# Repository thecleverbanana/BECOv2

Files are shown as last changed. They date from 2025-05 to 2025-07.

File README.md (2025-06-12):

# BECOv2
This repo is aimed for RoboLAND and experiment on Multi-Agent Robot

The repo is divided into four parts: Mega 2560, simulation, analysis and CAD 

### Mega 2560 
This part is directly communicating with our actual rebot using mega 2560 micro-controller unit. 

Before running the controller, please read followings:

#### A. Wiring 


There are two major connections:

1. **UART (RX/TX) with LSS motor**  
   **Important**: please double check the wire direction of the power and ground of the LSS wire:  [See official wiring guide](https://wiki.lynxmotion.com/info/wiki/lynxmotion/view/ses-v2/lynxmotion-smart-servo/lss-electrical/)
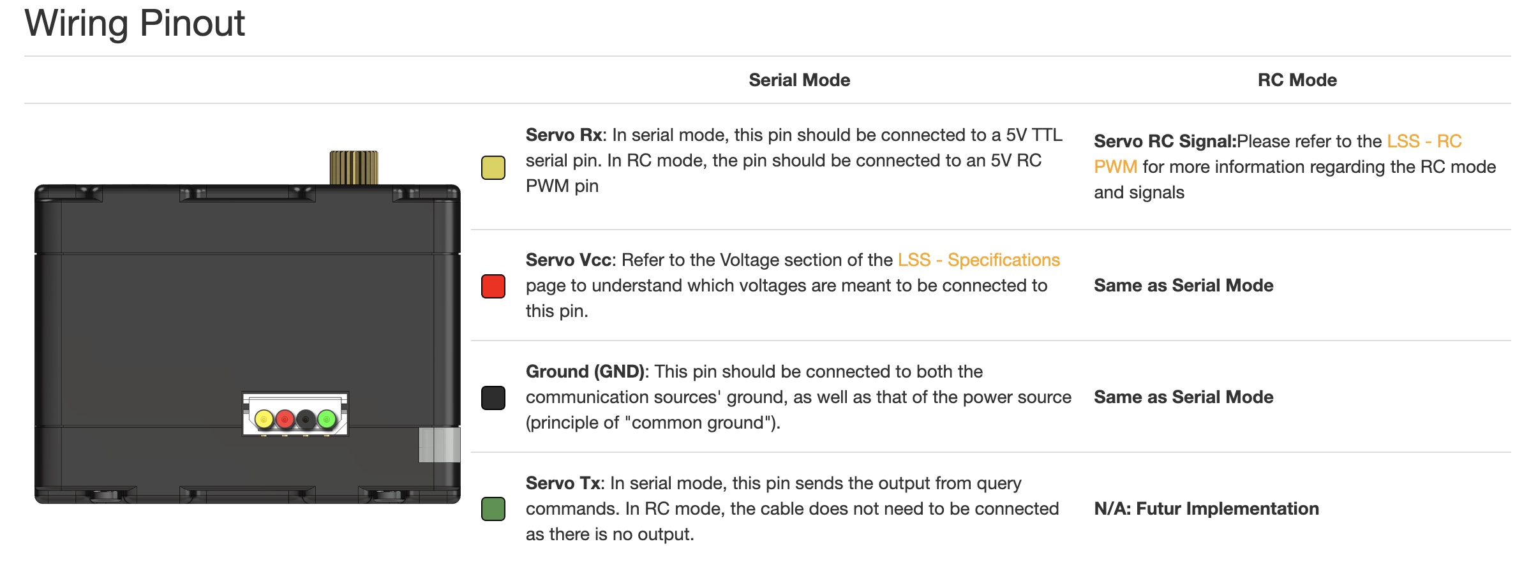
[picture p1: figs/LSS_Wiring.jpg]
     

   We used Serial1 from Mega 2560 to communicate with the motor, which corresponds to pin 18 (TX1) and pin 19 (RX1) on the board.

2. **PWM with linear actuator**  
   We used pin 4 (PWM capable) to connect with the linear actuator.  
   Make sure the blue wire matches the blue wire on the actuator.  
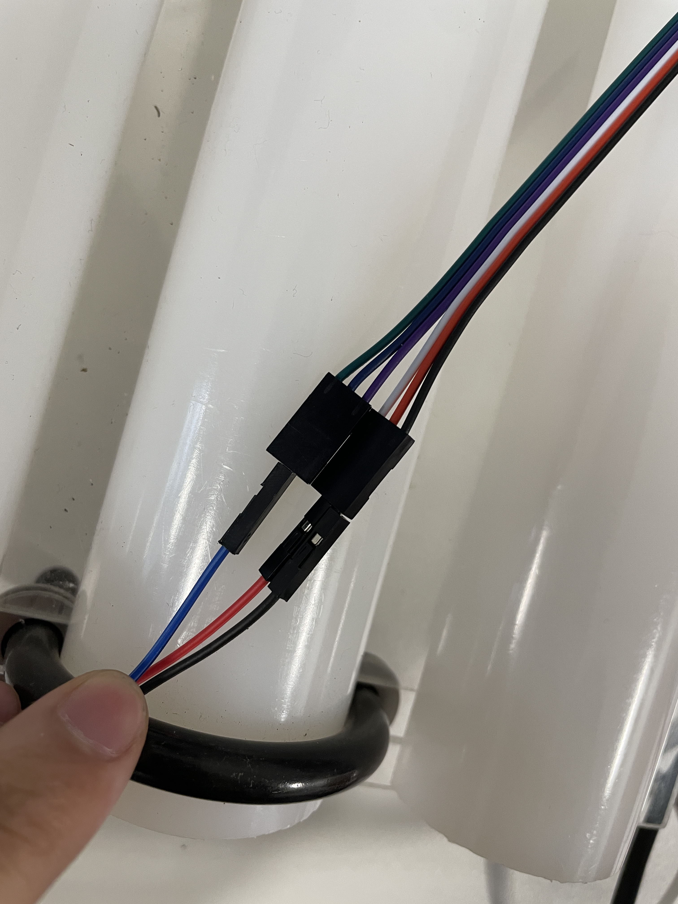
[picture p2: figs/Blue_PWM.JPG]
     

All the wiring directions are marked, please check the markers:  
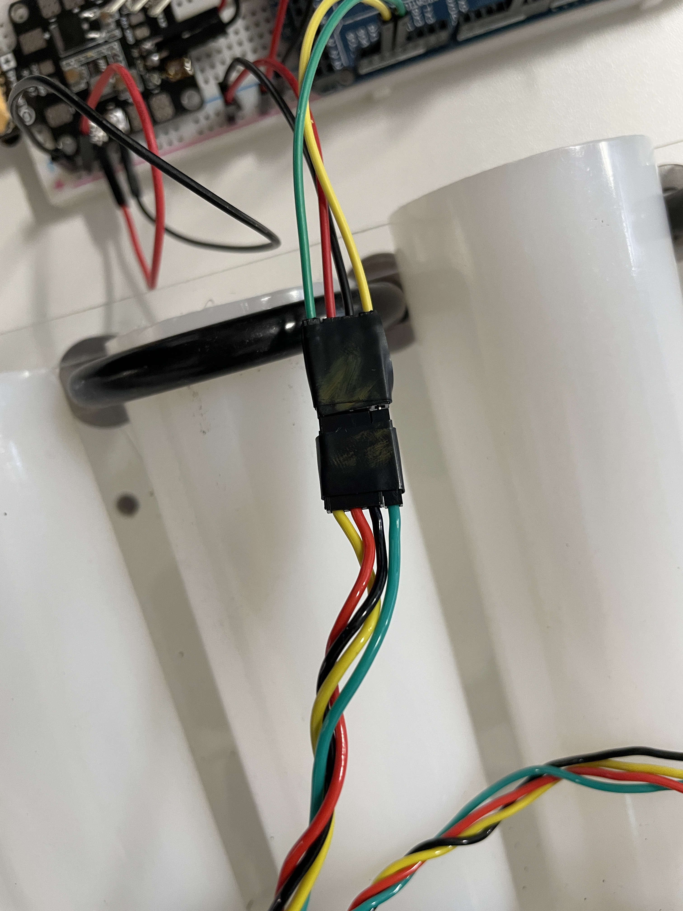
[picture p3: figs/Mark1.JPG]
    

#### B. Power
1. Power should be connected to the PDB with maxium 12V and minimum 6V. And current should never exceed 1A, 650mA is enough
2. Power for linear actuator and motor are both 12 V.
#### B. Coding
1. Download platformIO from vscode extensions
2. Main file in src, use platformIO to compile (main.cpp is the interface with platform io, if you want to run different code, simply copy code into main.cpp or modify compiling path in platformio.ini)

### Simulation
This part is used for robot simulation. We used the Webots and Gazebo as simulation platform.

### Analysis
All analysis code and documentation can be found here 

### CAD
All needed CAD files of our robot can be found here

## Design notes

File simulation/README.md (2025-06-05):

# Some useful commands and instructions for simulation

### urdf to proto    https://github.com/cyberbotics/urdf2webots 
python3 -m urdf2webots.importer \
  --input="/Users/jerrywu/Library/Mobile Documents/com~apple~CloudDocs/Desktop/Roboland/Multi-Agent/BECOv2/simulation/Webots/urdf/BECOV2.urdf" \
  --output="/Users/jerrywu/Library/Mobile Documents/com~apple~CloudDocs/Desktop/Roboland/Multi-Agent/BECOv2/simulation/Webots/protos/BECOV2BOX.proto" \
  --normal

### Solid format in world
Solid {
  translation 0 0 0 
  rotation 1 0 0 1.5708
  children [
    Shape {
      appearance PBRAppearance {
        baseColor 0.2 0.2 1.0
        roughness 0.5
        metalness 0.0
      }
      geometry Mesh {
        url "../../Blender/Terrain/terrain7/terrain7.obj"
      }
    }
  ]
  boundingObject Mesh {
    url "../../Blender/Terrain/terrain7/terrain7.obj"
  }
  physics Physics {
    mass 10
  }
  name "Terrain7"
}

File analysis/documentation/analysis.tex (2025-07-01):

\documentclass[11pt]{article}

% --- Encoding & Language ---
\usepackage[utf8]{inputenc}
\usepackage[T1]{fontenc}
\usepackage[english]{babel}

% --- Math Packages ---
\usepackage{amsmath, amssymb, amsfonts}
\usepackage{mathtools}
\usepackage{physics}          % for \dv, \pdv, \grad, etc.
\usepackage{bm}               % for bold math symbols
\usepackage{siunitx}          % for units

% --- Page Layout ---
\usepackage[margin=1in]{geometry}
\usepackage{setspace}
\onehalfspacing

% --- Theorem Environment ---
\usepackage{amsthm}
% Create a shared counter (let's call it 'statement') per section
\newtheorem{statement}{Statement}[section]
\newtheorem{theorem}[statement]{Theorem}
 
% Define 'assumption' and 'diagram' to use the same counter
\newtheorem{assumption}[statement]{Assumption}
\newtheorem{diagram}[statement]{Diagram}
\newtheorem{note}[statement]{Note}

% --- Figure & Table ---
\usepackage{graphicx}
\usepackage{float}
\usepackage{caption}
\usepackage{subcaption}
\usepackage{mwe}
% \includegraphics{example-image}
\usepackage{hyperref}

% --- TikZ for Diagrams ---
\usepackage{tikz}
\usetikzlibrary{arrows.meta, decorations.pathmorphing, patterns}

% --- Code Listings (optional) ---
\usepackage{listings}
\lstset{
  basicstyle=\ttfamily\small,
  frame=single,
  breaklines=true,
  postbreak=\mbox{\textcolor{red}{$\hookrightarrow$}\space},
}

% --- Title Info ---
\title{\textbf{Force Based Model Analysis}}
\author{Jerry Wu}
\date{\today}

\begin{document}

\maketitle
\noindent
\textbf{Helpful Link:}
\begin{itemize}
    \item \href{https://www.geogebra.org/classic/vzgc97bq}{Geogebra Demo}
    \item \href{https://www.canva.com/design/DAGo-OCr6Yo/K5YV57vaBxux-PqkqwI4ow/edit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}{Canva Graphics}
\end{itemize}

% \begin{assumption}\label{ass:leg-ground-contact}
% The end point of each leg is always contacting the ground.
% \end{assumption}

\begin{assumption}\label{ass: no-body-contact}
The robot body would never contact with the terrain
\end{assumption}

\begin{assumption}\label{ass: com}
The CoM of the robot is always at local geometric center in direction parrallel to Spine
\end{assumption}

\section{Statics}
\begin{assumption}
Static means the robot would not move and achieve static equilibrium in this state
\end{assumption}
\subsection*{Slope}

\begin{diagram}
    Simple case where two legs have same height
\end{diagram}\label{ass:h2-equal-h1}
\vspace{1ex} % small vertical space
\begin{center}
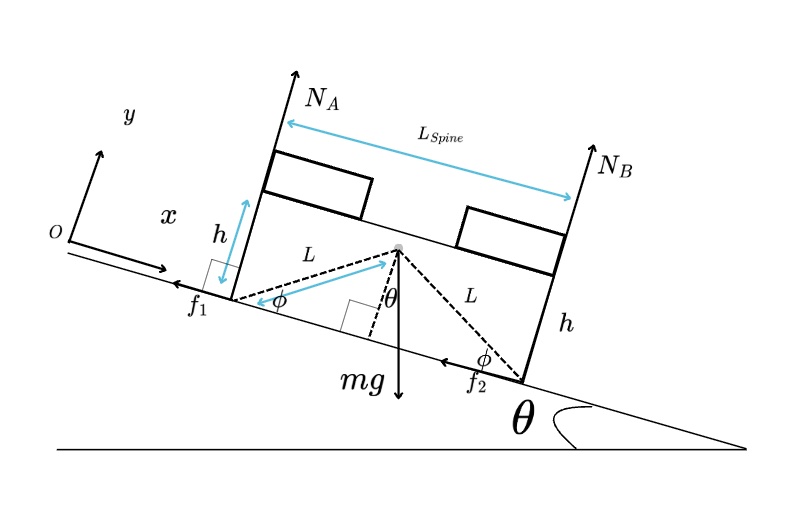
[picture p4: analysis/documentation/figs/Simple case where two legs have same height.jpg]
     % replace with your image
\end{center}

To start with,  we put robot on a slope with angle \(\theta\). To make the analysis easier,
assume that two leg have same height \(h\) in this case. Therefore, the moment arm are symetric
for \(R_A\) and \(R_B\). Therefore, we can get follow equations:
\[ \sum F_x = (f_1+f_2) - \sin(\theta)mg = 0 \]
\[ \sum F_y = (N_A+N_B) - \cos(\theta)mg = 0 \]
\[ \sum M_A = L_\text{spine} \cdot N_B -  L \cdot mg \cdot \sin(\frac{\pi}{2}-\phi+\theta) = 0 \]
\[ \sum M_B = L_\text{spine} \cdot N_A -  L \cdot mg \cdot \sin(\frac{\pi}{2}-\phi+\theta) = 0 \]

\begin{diagram}
    Two legs have different height
\end{diagram}\label{ass:h2-larger-than-h1}
\vspace{1ex} % small vertical space
\begin{center}
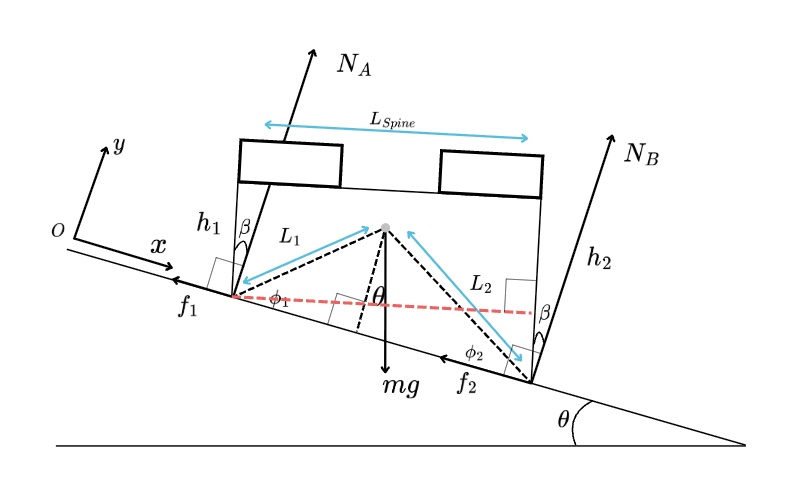
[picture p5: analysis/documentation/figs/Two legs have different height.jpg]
     % replace with your image
\end{center}

Now extend the case to where the leg length would change. Here the robot extended
the right leg to \(h_2\), which makes the robot rotate angle \(\beta\) around
the z-Axis. Now both moment arms on two legs are 
shifted. We can also form the static equilibrium equation as follows:

\[ \sum F_x = (f_1+f_2) - \sin(\theta)mg = 0 \]
\[ \sum F_y = (N_A+N_B) - \cos(\theta)mg = 0 \]
\[ \sum M_A = \frac{L_\text{spine}}{\sin(\frac{\pi}{2}-\beta)} \cdot N_B \cdot \sin(\frac{\pi}{2})-  L_1 \cdot mg \cdot \sin(\frac{\pi}{2}-\phi_1+\theta) = 0 \]
\[ \sum M_B = \frac{L_\text{spine}}{\sin(\frac{\pi}{2}-\beta)} \cdot N_A \cdot \sin(\frac{\pi}{2})-  L_2 \cdot mg \cdot \sin(\frac{\pi}{2}-\phi_2-\theta) = 0 \]

based on the geometry of our robot, we can also formulate:
\[L_\text{spine} \cdot \cos(\frac{\pi}{2}-\beta) = h_2 - h_1 \]

\begin{note}\label{not:what-is-known}
\(h_1\), \(h_2\) are known values, so \(\beta\) is also known.  
Therefore, \(\phi_1\) and \(\phi_2\) can easily be solved using Theorem~\ref{thm:law-of-cosines}.
\end{note}

\begin{theorem}\label{thm:law-of-cosines}
Law of Cosines

\[
\cos A = \frac{b^2 + c^2 - a^2}{2bc}
\]
\[
\cos B = \frac{a^2 + c^2 - b^2}{2ac}
\]
\[
\cos C = \frac{a^2 + b^2 - c^2}{2ab}
\]
\end{theorem}

\subsection*{Zig-Zag Terrain}

\begin{assumption}\label{ass:Zig-Zag-terrain-assumption}
The terrain is uniform that all triangle obstable and gap between them are same
\end{assumption}

A natural extension for the slope is triangle terrain. There are esseintially five cases
when robot is static on the triangle terrain: 1. two legs on the same slope 2. two legs on two slopes that face each other
3. two legs on two slopes that does not face each other 4. one leg is on the slope and the other is on the gap. 5. two legs
are all on the gap. 

For case 1, we have already discussed in the previous section. And for case 5, it is esseintially the same
like slope when \(\theta\) is 0.

\begin{diagram}
    Case2: two legs on the slope that face each other
\end{diagram}
\vspace{1ex} % small vertical space
\begin{center}
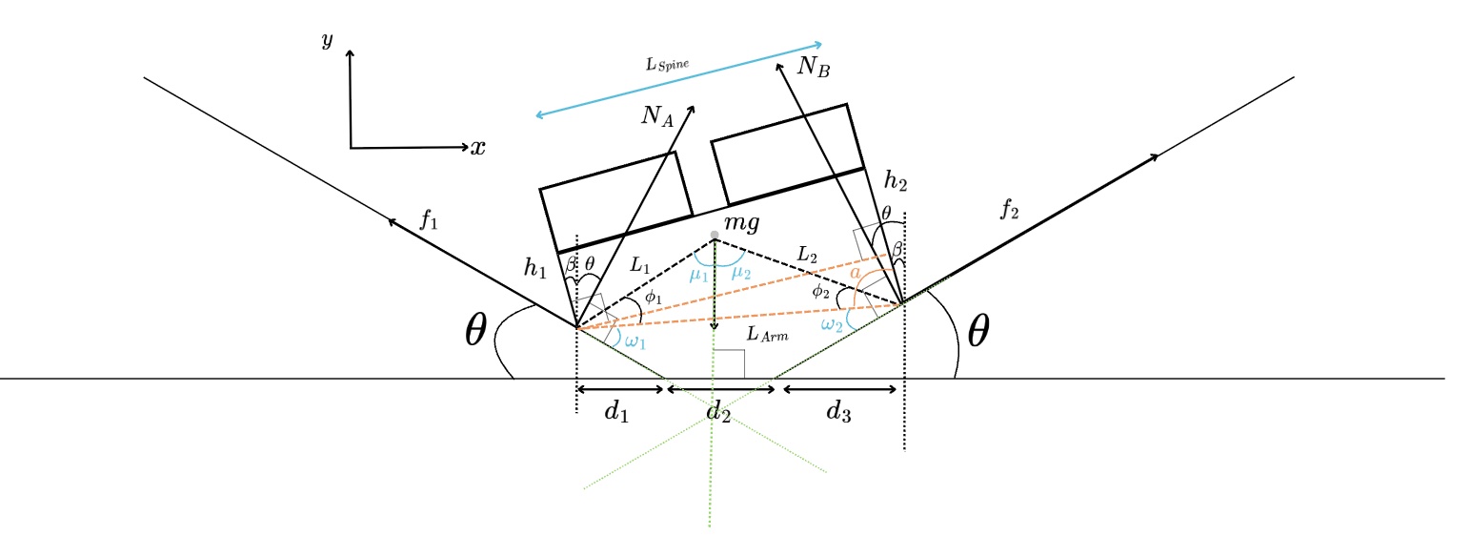
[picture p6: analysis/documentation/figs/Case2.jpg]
     % replace with your image
\end{center}

To make it clearer, I changed the coordinate that aligns with the ground rather slope from now on.
We can also formulate the equilibrium equations:

\[ \sum F_x = (-f_1+f_2)\cos(\theta) + (N_A-N_B) \sin(\theta) = 0 \]
\[ \sum F_y = (f_1+f_2)\sin(\theta) + (N_A+N_B) \cos(\theta) - mg = 0 \]
\[ \sum M_A =  L_\text{Arm} \cdot (N_B \cdot \sin(\frac{\pi}{2}-\omega_2) + f_2 \cdot \sin(\pi-\omega_2)) - L_1\cdot mg \cdot \sin(\mu_1)= 0 \]
\[ \sum M_B =  L_\text{Arm} \cdot (N_B \cdot \sin(\frac{\pi}{2}-\omega_1) + f_1 \cdot \sin(\pi-\omega_1)) - L_2\cdot mg \cdot \sin(\mu_2)= 0 \]

where by geometry of the shape, we can find:
\[\omega_1 = (\theta + \beta)  - (\frac{\pi}{2}-\alpha) \]
\[\omega_2 = (\theta - \beta) + (\frac{\pi}{2}-\alpha) \]
\[\mu_1 = \pi-(\phi_1+\omega_1)-(\frac{\pi}{2}-\theta) \]
\[\mu_2 = \pi-(\phi_2+\omega_2)-(\frac{\pi}{2}-\theta) \]
\[\alpha = \arctan(\frac{L_\text{Spine}}{h2-h1}) \]
\[L_\text{Arm} = \sin(\alpha) \cdot L_\text{Spine}\]

similarly to Note~\ref{not:what-is-known}, this equalion can be solved.

\begin{diagram}
    Case3: two legs on two slopes that do not face each other
\end{diagram}
\vspace{1ex} % small vertical space
\begin{center}
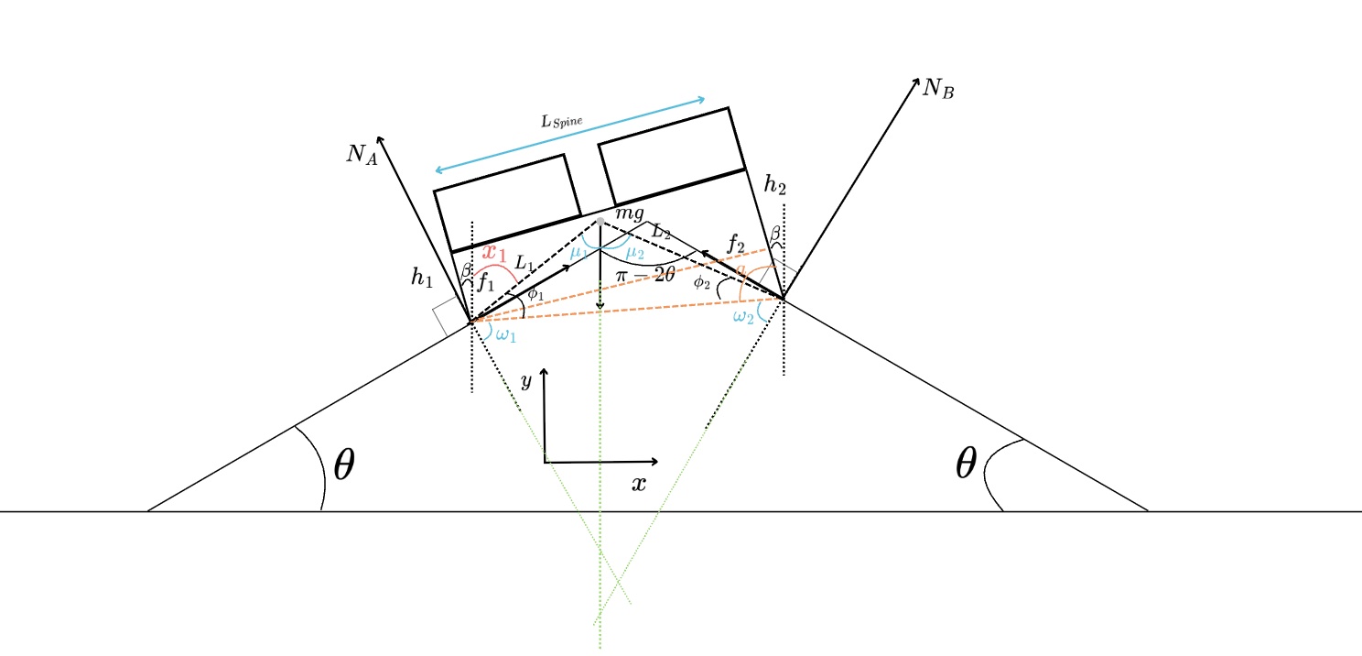
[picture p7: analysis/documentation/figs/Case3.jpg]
     % replace with your image
\end{center}

\[ \sum F_x = (f_1-f_2)\cos(\theta) + (-N_A+N_B) \sin(\theta) = 0 \]
\[ \sum F_y = (f_1-f_2)\sin(\theta) + (-N_A+N_B) \cos(\theta) - mg = 0 \]
\[ \sum M_A =  L_\text{Arm} \cdot (N_B \cdot \sin(\pi-\omega_2) + f_2 \cdot \sin(\frac{\pi}{2}-\omega_2)) - L_1\cdot mg \cdot \sin(\mu_1)= 0 \]
\[ \sum M_B =  L_\text{Arm} \cdot (N_A \cdot \sin(\pi-\omega_1) + f_1 \cdot \sin(\frac{\pi}{2}-\omega_1)) - L_2\cdot mg \cdot \sin(\mu_2)= 0 \]

where by geometry of the shape, we can find:
\[\omega_1 = \beta + \alpha - \theta\]
\[\omega_2 =  \pi - \beta - \alpha - \theta\]
\[\mu_1 = \pi-(\phi_1+\omega_1)-\theta \]
\[\mu_2 = \pi-(\phi_2+\omega_2)-\theta \]
\[\alpha = \arctan(\frac{L_\text{Spine}}{h2-h1}) \]
\[L_\text{Arm} = \sin(\alpha) \cdot L_\text{Spine}\]

\begin{note}
The equation for \(\omega_1\)  can be found specifically by following equation:
\end{note}
\begin{equation}
x_1 + \phi_1 + \omega_1 + \theta = \pi
\end{equation}

\begin{equation}
\beta + x_1 + \phi_1 - \left( \frac{\pi}{2} - \alpha \right) = \frac{\pi}{2}
\end{equation}

\begin{equation}
\omega_1 = \beta + \alpha - \theta
\tag*{From (1) and (2)}
\end{equation}

\begin{diagram}
    Case4: one leg is on the slope and the other is on the gap
\end{diagram}
\vspace{1ex} % small vertical space
\begin{center}
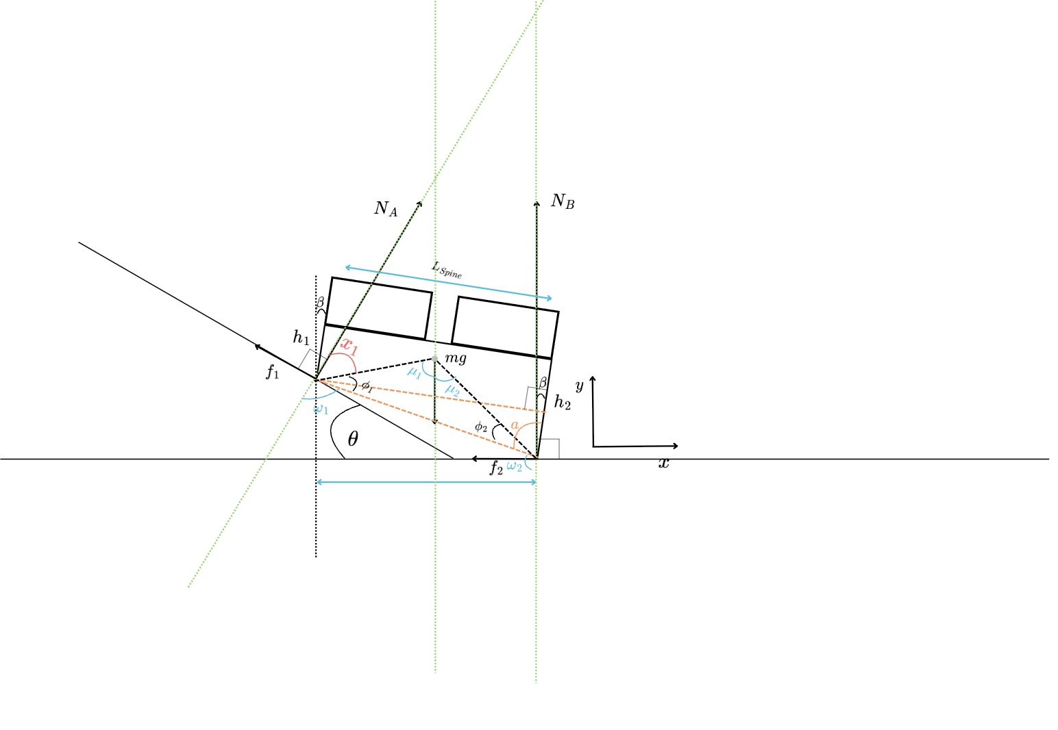
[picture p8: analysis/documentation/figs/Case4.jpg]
     % replace with your image
\end{center}

\[ \sum F_x = -f_1 \cos(\theta) -f_2 + N_A \sin(\theta)= 0 \]
\[ \sum F_y = f_1 \sin(\theta)+ N_A \cos(\theta) + N_B - mg = 0 \]
\[ \sum M_A =  L_\text{Arm} \cdot (N_B \cdot \sin(\pi-\omega_2) + f_2 \cdot \sin(\frac{\pi}{2}-\omega_2)) - L_1\cdot mg \cdot \sin(\mu_1)= 0 \]
\[ \sum M_B =  L_\text{Arm} \cdot (N_B \cdot \sin(\pi-\omega_1) + f_1 \cdot \sin(\frac{3\pi}{2}-\omega_1)) - L_2\cdot mg \cdot \sin(\mu_2)= 0 \]

where by geometry of the shape, we can find:
\[\omega_1 = \theta - \beta + \alpha\]
\[\omega_2 =  \pi + \beta - \alpha \]
\[\mu_1 = \pi-(\phi_1+\omega_1)-\theta \]
\[\mu_2 = \pi-(\phi_2+\omega_2) \]
\[\alpha = \arctan(\frac{L_\text{Spine}}{h2-h1}) \]
\[L_\text{Arm} = \sin(\alpha) \cdot L_\text{Spine}\]

\begin{note}
The equation for \(\omega_1\)  can be found specifically by following equation:
\end{note}
\begin{equation}
x_1 + \phi_1 + \omega_1 = \pi
\end{equation}

\begin{equation}
\theta-\beta + x_1 + \phi_1 - \left( \frac{\pi}{2} - \alpha \right) = \frac{\pi}{2}
\end{equation}

\begin{equation}
\omega_1 = \theta - \beta + \alpha
\tag*{From (1) and (2)}
\end{equation}

Now, by observation, this case is very similar to previous case. In fact, all of the above cases
are geometrically similar, which means we can find a general expression for this force based model.

\begin{diagram}
    Determine the geometry shape by robot body and terrain
\end{diagram}
\vspace{1ex} % small vertical space
\begin{center}
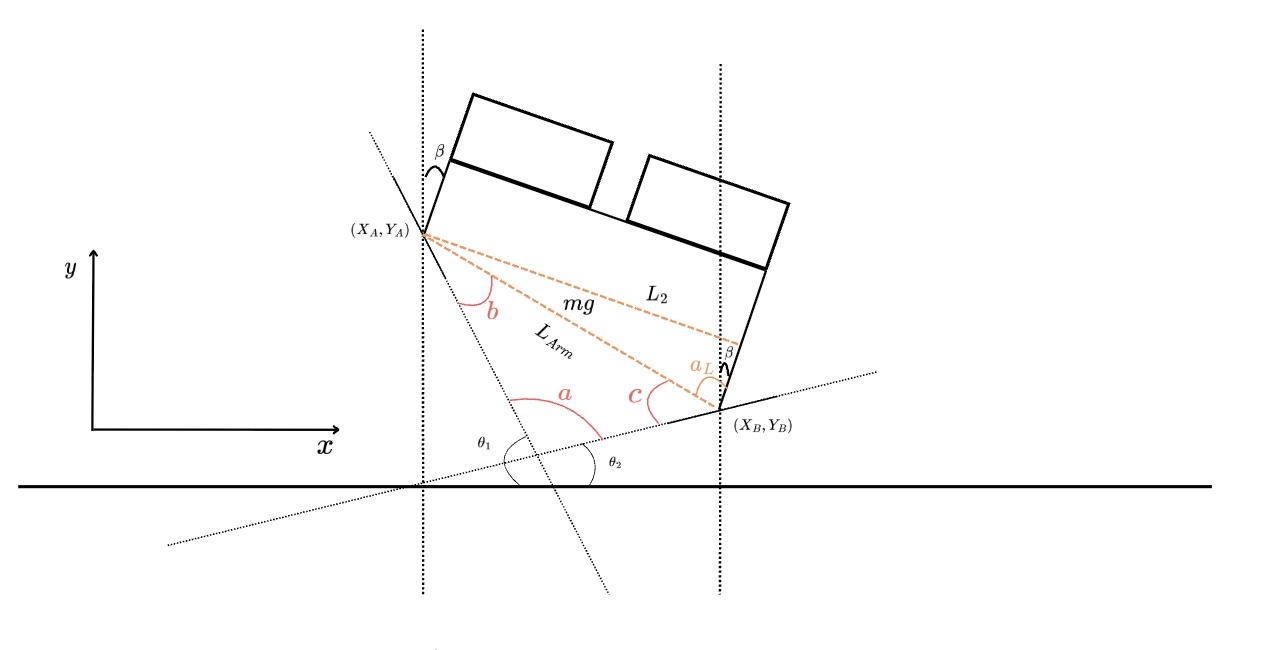
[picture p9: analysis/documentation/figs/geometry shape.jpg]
     % replace with your image
\end{center}

After simplifying the model, it can be seen that given the terrain tangent angle \(\theta_1\), \(\theta_2\), robot pitch
angle \(\beta\) and length of the virtual link between end point of two leg \(L_{Arm}\) we can determine the triangle with
inner angle \(a,b,c\). 

Here is how we determine angle \(a, b, c\):
\[a = \pi - \theta_1 - \theta_2\]
\[b = \pi - \beta - \frac{\pi}{2}-(\frac{\pi}{2}-\alpha_L)-(\pi-\theta_1)\]
\[c = \pi - (\pi-\theta_2) + \beta - \alpha_L\]

by verification: 
\[a+b+c = \pi\]

As for different tangent angles, this property should hold as well. This means there would be \textbf{only one solution} by
given condition.

\begin{diagram}
    Generailized Free Body Diagram
\end{diagram}
\vspace{1ex} % small vertical space
\begin{center}
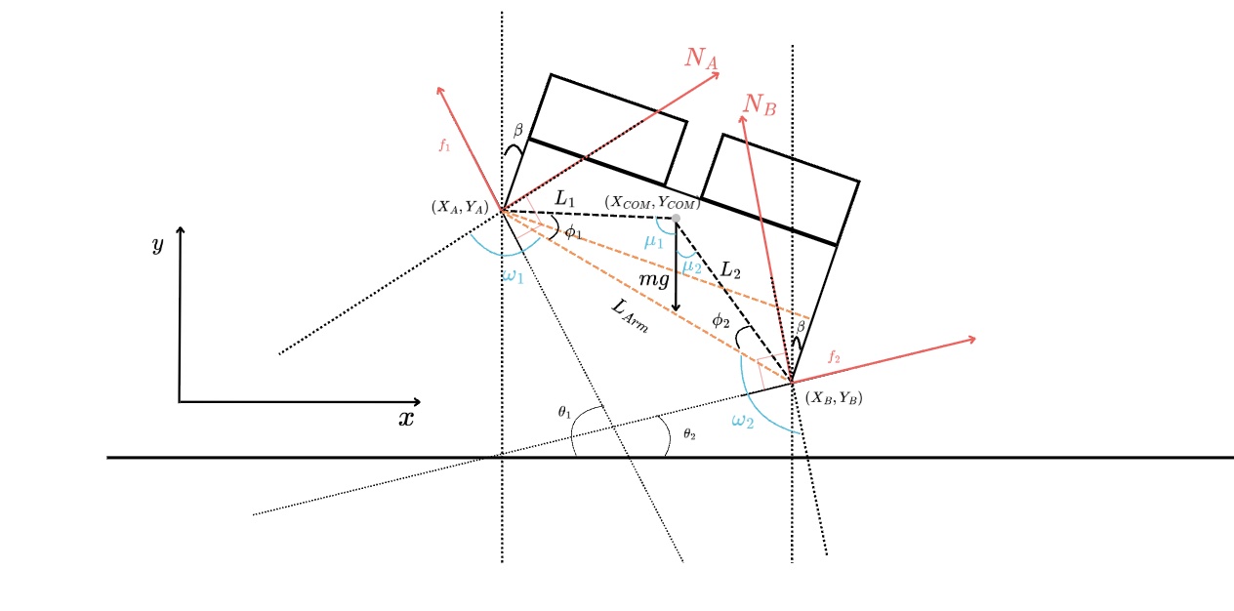
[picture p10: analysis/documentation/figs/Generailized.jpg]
     % replace with your image
\end{center}

Given the determined geometric shape of the robot and terrain, we can easily find the position of the COM through
the given of relative position \(L_1\) and \(L_2\), which can be solved by the geometry as well. Which means, if we put
the robot into coordinate, the points \((X_A, Y_A), (X_B, Y_B), (X_{COM}, Y_{COM})\) are given.

Therefore, given \((X_A, Y_A), (X_B, Y_B), (X_{COM}, Y_{COM}), \theta_1, \theta_2\), \(L_{Spine}\) we can formulate
\[
\sum \vec{F} = \vec{f}_1 + \vec{f}_2 + \vec{N}_A + \vec{N}_B + \vec{W} = \vec{0}
\]

\[
\sum \vec{M}_A = 
(\vec{r}_B - \vec{r}_A) \times (\vec{f}_2 + \vec{N}_B)
+ (\vec{r}_{\text{COM}} - \vec{r}_A) \times \vec{W}
= 0
\]

\[
\sum \vec{M}_B = 
(\vec{r}_A - \vec{r}_B) \times (\vec{f}_1 + \vec{N}_A)
+ (\vec{r}_{\text{COM}} - \vec{r}_B) \times \vec{W}
= 0
\]

where
\begin{align*}
\hat{t}_1 &= (\cos(\pi-\theta_1),\; \sin(\pi-\theta_1)) \quad \text{(contact tangent 1)} \\
\hat{n}_1 &= (-\sin(\pi-\theta_1),\; \cos(\pi-\theta_1)) \quad \text{(contact normal 1)} \\
\hat{t}_2 &= (\cos\theta_2,\; \sin\theta_2) \\
\hat{n}_2 &= (-\sin\theta_2,\; \cos\theta_2)
\end{align*}

\begin{align*}
\vec{f}_1 &= f_1 \cdot \hat{t}_1 = f_1 \cdot (\cos(\pi-\theta_1),\; \sin(\pi-\theta_1)) \\
\vec{N}_A &= N_A \cdot \hat{n}_1 = N_A \cdot (-\sin(\pi-\theta_1),\; \cos(\pi-\theta_1)) \\
\vec{f}_2 &= f_2 \cdot \hat{t}_2 = f_2 \cdot (\cos\theta_2,\; \sin\theta_2) \\
\vec{N}_B &= N_B \cdot \hat{n}_2 = N_B \cdot (-\sin\theta_2,\; \cos\theta_2) \\
\vec{W}   &= -mg \cdot (0,\; 1)
\end{align*}

\begin{align*}
\text{Moment arm of } \vec{f}_2, \vec{N}_B \text{ about A}: \quad
& \vec{r}_{f_2/A} = \vec{r}_B - \vec{r}_A = (X_B - X_A,\; Y_B - Y_A) \\
\text{Moment arm of } \vec{W} \text{ about A}: \quad
& \vec{r}_{W/A} = \vec{r}_{\text{COM}} - \vec{r}_A = (X_{COM} - X_A,\; Y_{COM} - Y_A) \\[1ex]
\text{Moment arm of } \vec{f}_1, \vec{N}_A \text{ about B}: \quad
& \vec{r}_{f_1/B} = \vec{r}_A - \vec{r}_B = (X_A - X_B,\; Y_A - Y_B) \\
\text{Moment arm of } \vec{W} \text{ about B}: \quad
& \vec{r}_{W/B} = \vec{r}_{\text{COM}} - \vec{r}_B = (X_{COM} - X_B,\; Y_{COM} - Y_B)
\end{align*}

Therefore,
\begin{align*}
    \sum \vec{F}_x &= -f_1 \cos\theta_1 + f_2 \cos\theta_2 
                     - N_A \sin\theta_1 - N_B \sin\theta_2 = 0 \\
    \sum \vec{F}_y &= f_1 \sin\theta_1 + f_2 \sin\theta_2 
                     - N_A \cos\theta_1 + N_B \cos\theta_2 - mg = 0 \\[1ex]
    \sum \vec{M}_A &= (X_B - X_A)(f_2 \sin\theta_2 + N_B \cos\theta_2)
                     - (Y_B - Y_A)(f_2 \cos\theta_2 - N_B \sin\theta_2)
                     - mg (X_{\text{COM}} - X_A) = 0 \\
    \sum \vec{M}_B &= (X_A - X_B)(f_1 \sin\theta_1 - N_A \cos\theta_1)
                     - (Y_A - Y_B)(-f_1 \cos\theta_1 - N_A \sin\theta_1)
                     - mg (X_{\text{COM}} - X_B) = 0
\end{align*}

solve,
\begin{align*}
    N_A &= \frac{g m (X_B - X_{\text{COM}}) \cos\theta_1}{X_A - X_B} \\[1ex]
    N_B &= \frac{g m (X_A - X_{\text{COM}}) \cos\theta_2}{X_A - X_B} \\[1ex]
    f_1 &= \frac{g m (X_{\text{COM}} - X_B) \sin\theta_1}{X_A - X_B} \\[1ex]
    f_2 &= \frac{g m (X_A - X_{\text{COM}}) \sin\theta_2}{X_A - X_B}
\end{align*}
    
By friction function \(\left| f \right| \leq \mu N\), we can solve this equation and find 

\begin{align*}
    \left| f_1 \right| &= \left| \frac{g m (X_{\text{COM}} - X_B) \sin\theta_1}{X_A - X_B} \right| 
    \leq \mu \cdot \frac{g m (X_B - X_{\text{COM}}) \cos\theta_1}{X_A - X_B} = \mu N_A \\[1.5ex]
    \left| f_2 \right| &= \left| \frac{g m (X_A - X_{\text{COM}}) \sin\theta_2}{X_A - X_B} \right| 
    \leq \mu \cdot \frac{g m (X_A - X_{\text{COM}}) \cos\theta_2}{X_A - X_B} = \mu N_B
\end{align*}

% \begin{note}
    The above expression is derived in case where the \(\theta_1\) and \(\theta_2\) are both acute angles from graphic
    definition, but it is clear that in other cases, they are the same, a even more genral expression is actually:
% \end{note}

\begin{align*}
    \vec{f}_1 &= f_1 \cdot \hat{t}_1 \\
    \vec{N}_A &= N_A \cdot \hat{n}_1 \\
    \vec{f}_2 &= f_2 \cdot \hat{t}_2 \\
    \vec{N}_B &= N_B \cdot \hat{n}_2 \\
    \vec{W}   &= -mg \cdot (0,\; 1) \\
\end{align*}
\begin{align*}
    \sum F_x &= f_1 t_{1x} + f_2 t_{2x} + N_A n_{1x} + N_B n_{2x} = 0 \\
    \sum F_y &= f_1 t_{1y} + f_2 t_{2y} + N_A n_{1y} + N_B n_{2y} - mg = 0 \\
    \sum M_A &= 
    (x_B - x_A)(f_2 t_{2y} + N_B n_{2y}) - (y_B - y_A)(f_2 t_{2x} + N_B n_{2x}) \notag \\
    &\quad - mg (x_{COM} - x_A) = 0 \\
    \sum M_B &= 
    (x_A - x_B)(f_1 t_{1y} + N_A n_{1y}) - (y_A - y_B)(f_1 t_{1x} + N_A n_{1x}) \notag \\
    &\quad - mg (x_{COM} - x_B) = 0
\end{align*}
In matrix form: 
\begin{align*}
    \scriptsize
    \left[
    \begin{array}{cccc}
    t_{1x} & t_{2x} & n_{1x} & n_{2x} \\
    t_{1y} & t_{2y} & n_{1y} & n_{2y} \\
    0 & \Delta x_{BA} t_{2y} - \Delta y_{BA} t_{2x} 
      & 0 & \Delta x_{BA} n_{2y} - \Delta y_{BA} n_{2x} \\
    \Delta x_{AB} t_{1y} - \Delta y_{AB} t_{1x} 
      & 0 & \Delta x_{AB} n_{1y} - \Delta y_{AB} n_{1x} 
      & 0
    \end{array}
    \right]
    \cdot
    \begin{bmatrix}
    f_1 \\ f_2 \\ N_A \\ N_B
    \end{bmatrix}
    =
    \begin{bmatrix}
    0 \\
    mg \\
    mg (x_{\text{COM}} - x_A) \\
    mg (x_{\text{COM}} - x_B)
    \end{bmatrix}
    \normalsize
\end{align*}
    
\paragraph{Friction Cone Constraints}
\[
|\vec{f}_1| \leq \mu |N_A|, \quad 
|\vec{f}_2| \leq \mu |N_B|
\]

\subsection*{Cylinder Terrain}

\begin{diagram}
    Generailized expression on Cylinder Terrain
\end{diagram}
\vspace{1ex} % small vertical space
\begin{center}
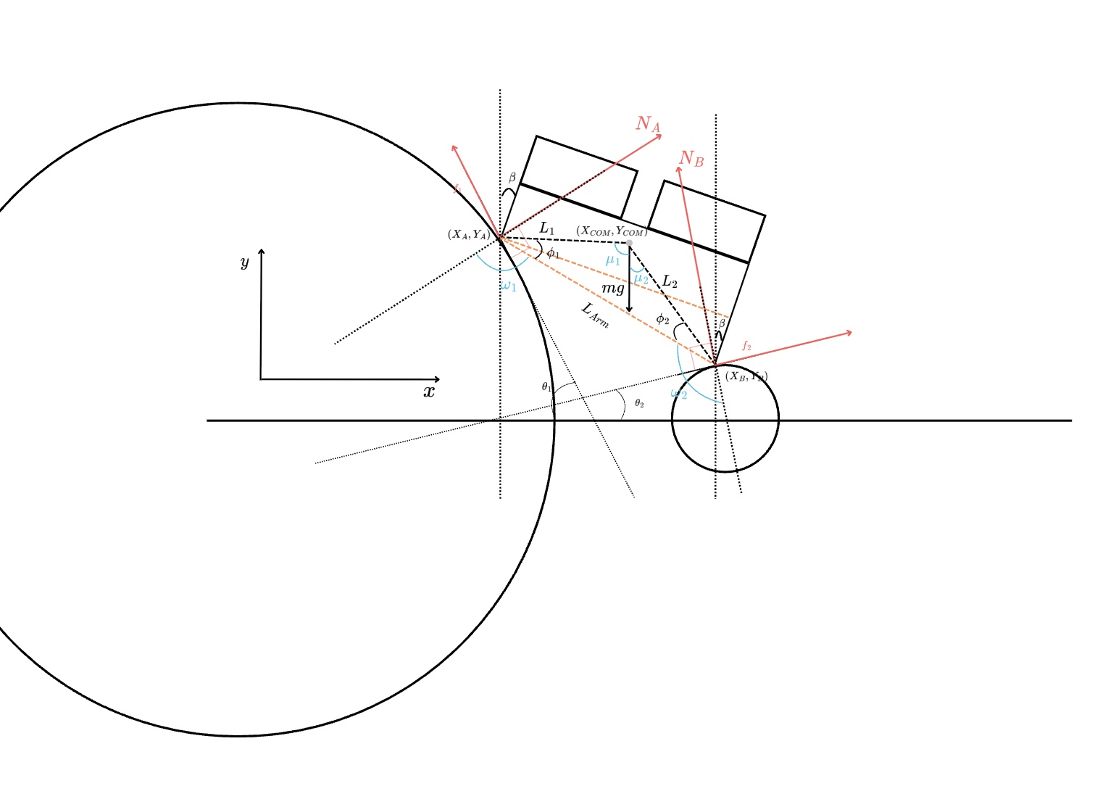
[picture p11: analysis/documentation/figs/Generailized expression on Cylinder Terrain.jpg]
     % replace with your image
\end{center}

With the general expression, we can directly put the same graph within in a cylinder terrian, where
\(\theta_1\) and \(\theta_2\) are esseintially the tangent line with the cylinder. 

\begin{diagram}
    Impossible case under Assumption \ref{ass:leg-ground-contact}
\end{diagram}
\vspace{1ex} % small vertical space
\begin{center}
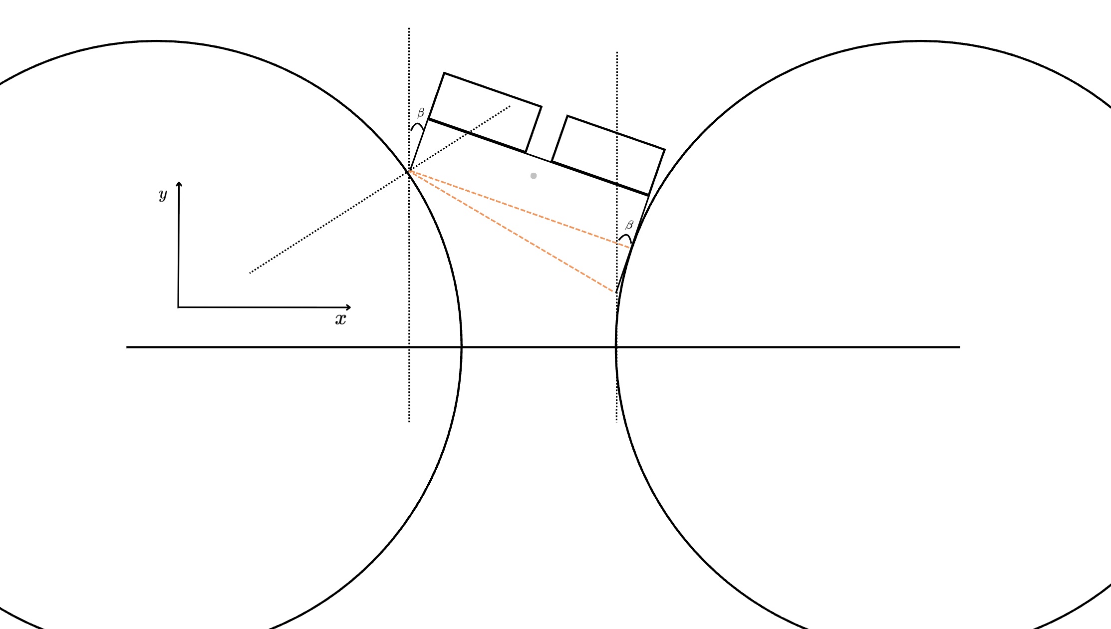
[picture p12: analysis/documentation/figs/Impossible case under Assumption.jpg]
     % replace with your image
\end{center}

However, here, it is impossible that right leg is still contacting the ground due to \(\beta\). In this case, the generalized 
geometric is not applied completely, which requires furthur discuss by changing the assumption \ref{ass:leg-ground-contact}. 

However, this case can also be determined geometrically. Now let's firstly simplify the problem
that all cylinder shape on this terrain has same radius. 

\subsubsection*{Cylinder Terrain when radius are identical}

I made a simple demo for robot geometric shape can be found in this \href{https://www.geogebra.org/classic/vzgc97bq}{GeoGebra link}.
Here A represents the contact point of left leg on the left circle and AB represents of \(L_{Spine}\). The
moving P point represents the right leg extension and AP represents the \(L_{Arm}\).For both folowing cases, 
we form equations as follows in coordinates:

\begin{note}
    In this terrain, what we actually want to consider is given the shape of the cylinder
    (i.e radius and gap), how can we find the \(\theta_1\) and \(\theta_2\).
\end{note}

\begin{diagram}
    When Point P contacts the terrain
\end{diagram}
\vspace{1ex} % small vertical space
\begin{center}
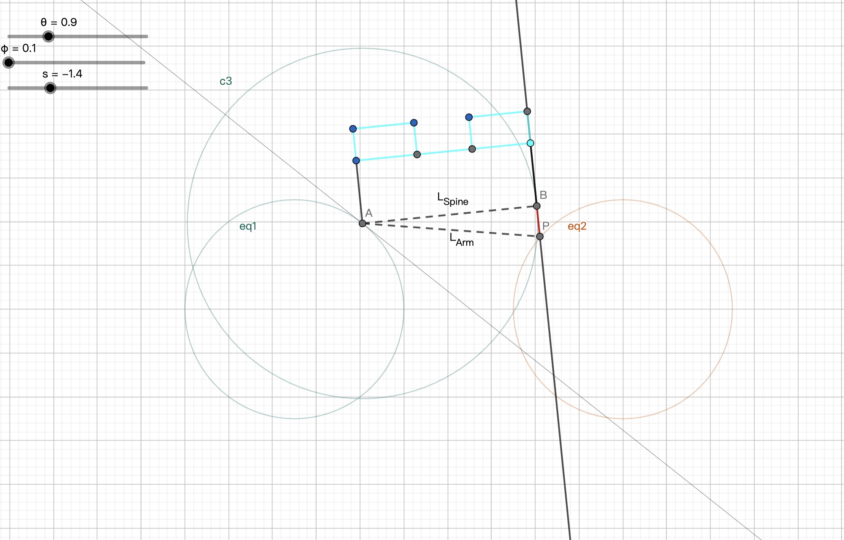
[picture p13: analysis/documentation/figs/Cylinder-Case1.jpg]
     % replace with your image
\end{center}

\begin{diagram}
    When Segment tangents the terrain
\end{diagram}
\vspace{1ex} % small vertical space
\begin{center}
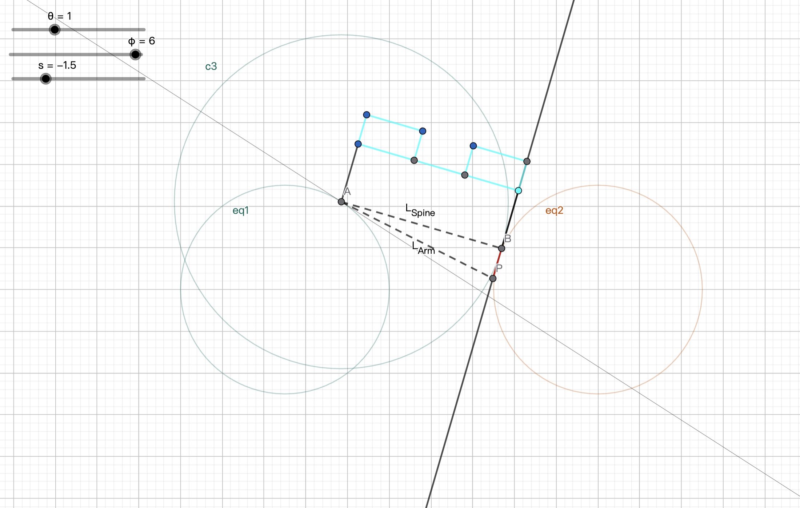
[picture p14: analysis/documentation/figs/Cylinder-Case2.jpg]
     % replace with your image
\end{center}

\noindent\textbf{Obstacle and Terrain Representation}
\begin{align*}
    &\text{Obstacle } c_1&& (x - c_1)^2 + y^2 = r^2 \\\\
    &\text{Obstacle } c_2&& (x - c_2)^2 + y^2 = r^2
\end{align*}

% \noindent\textbf{Flat Terrain Between Obstacles:}
% \begin{equation*}
% \text{TerrainHeight}(x) =
% \begin{cases}
%     h_{\text{obs}}, & x < c_1 - r \\\\
%     h_{\text{gap}}, & c_1 + r \leq x \leq c_2 - r \\\\
%     h_{\text{obs}}, & x > c_2 + r \\\\
%     \text{undefined (wall)}, & \text{otherwise}
% \end{cases}
% \end{equation*}

\vspace{1em}
\noindent\textbf{Control Parameters}
\begin{align*}
    \theta &\in [0, \pi] 
    && \text{\small (defines point $A$ on the upper half of the circle centered at $c_1$)} \\ 
    \varphi &\in [0, 2\pi] 
    && \text{\small (controls the direction of the robot spine extended from point $A$)} \\ 
    s &\in [-L_{\text{leg}}, 0]
    && \text{\small (represents the extension length of the right leg from point $B$)}
\end{align*}

\vspace{1em}
\noindent\textbf{Point Definitions}
\begin{align*}
    A &= (x_0, y_0) = \left(c_1 + r \cos \theta,\ r \sin \theta\right) \\
    B &= (x_1, y_1) = \left(x_0 + L_{\text{spine}} \cos \varphi,\ y_0 + L_{\text{spine}} \sin \varphi\right)
\end{align*}
\vspace{1em}
\noindent\textbf{Body Reachability Circle}
\begin{align*}
    c_A: \quad (x - x_0)^2 + (y - y_0)^2 = L_{Spine}^2
\end{align*}

\vspace{1em}
\noindent\textbf{Direction Vector and Point P}
\begin{align*}
    \vec{t} &= (t_x, t_y) = (-\sin \varphi,\ \cos \varphi) \\
    P &= (x_P, y_P) = (x_1 + s t_x,\ y_1 + s t_y)
\end{align*}

% \vspace{1em}
% \noindent\textbf{Distances}
% \begin{align*}
%     L_{\text{arm}} &= \| \vec{AP} \| = \sqrt{(x_P - x_0)^2 + (y_P - y_0)^2} \\
%     L_{\text{spine}} &= \| \vec{AB} \| = \sqrt{(x_1 - x_0)^2 + (y_1 - y_0)^2}
% \end{align*}

\vspace{1em}
\noindent\textbf{Collision Condition}
% \begin{align*}
%     \text{InsideObstacle2}(P) &= (x_P - c_2)^2 + y_P^2 < r^2 \tag{\text{\small Point $P$ must remain outside Obstacle 2.}}
% \end{align*}
Generally speaking, segment \(\overline{BP}\)  must intersect the boundary of Obstacle 2 exactly once:
\begin{align*}
    \left| \overline{BP} \cap \partial c_2 \right| &= 1 \\
    \overline{BP} \cap c_2^\circ &= \emptyset
\end{align*}

% \noindent\textbf{Collision Condition (Point $(x, y)$ inside obstacle):}
% \begin{align*}
%     \text{InsideObstacle} &= \left[(x - c_1)^2 + y^2 < r^2\right] \lor \left[(x - c_2)^2 + y^2 < r^2\right]
% \end{align*}

\subsubsection*{Case1}
\indent \indent In this case, it is very similar to what we did in the previous sections that we would consider 
pitch angle \(\beta\) in consideration. With that, we can determine triangle with knowning that A and P are 
on \(c_1\) and \(c_2\) and their angle.

\begin{diagram}
    Determine the geometric shape
\end{diagram}
\vspace{1ex} % small vertical space
\begin{center}
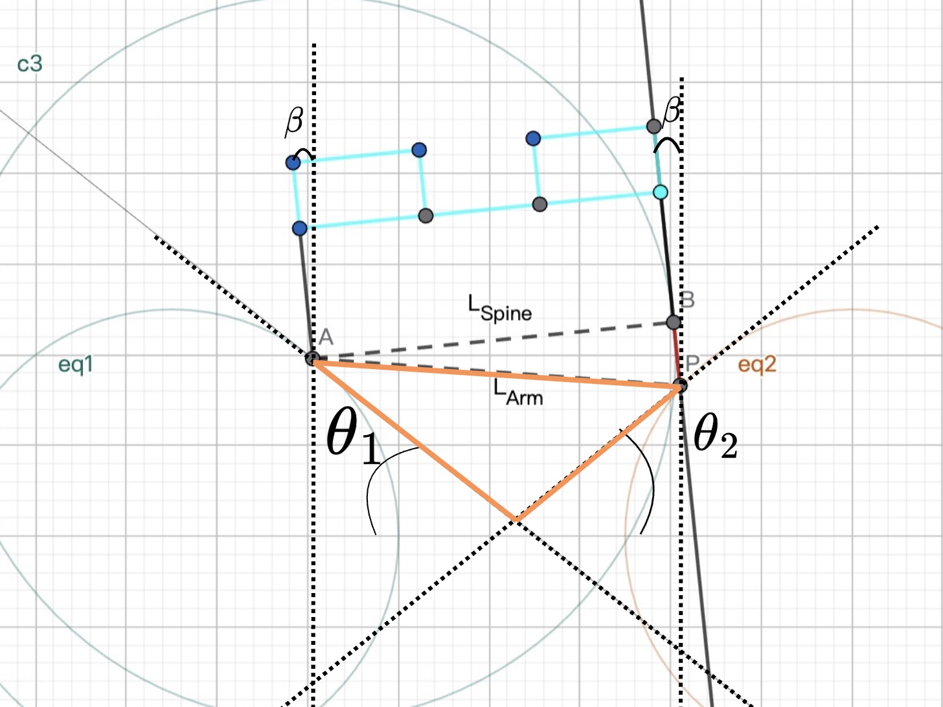
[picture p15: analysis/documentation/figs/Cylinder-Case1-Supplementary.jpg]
     % replace with your image
\end{center}

\begin{itemize}
    \item Two circles $c_1$ and $c_2$ with centers $C_1 = (x_1, y_1)$ and $C_2 = (x_2, y_2)$ respectively, both of radius $r$.
    \item Unknown points $A \in \partial c_1$, $P \in \partial c_2$.
    \item Length $L = \|A - P\|$ is known.
    \item Direction angle of $\vec{AP}$ is known: $\psi \in [0, 2\pi]$ from pitch angle \(\beta\).
\end{itemize}

\begin{note}
    To be more specific, direction angle is derived from both the geometric angle formed by triangle
    ABP and \(\beta\) .
\end{note}

Then the direction vector is:
\[
\vec{d} = \vec{AP} = L(\cos \psi, \sin \psi)
\]

We parameterize:
\begin{align*}
A &= (x_A, y_A) \\
P &= A + \vec{d} = (x_A + L \cos \psi,\ y_A + L \sin \psi)
\end{align*}

Apply the circle constraints:
\begin{align*}
\|A - C_1\|^2 &= r^2 \tag{1} \\
\|P - C_2\|^2 &= r^2 \tag{2}
\end{align*}

Substituting into (2):
\begin{align*}
&\left( x_A + L \cos \psi - x_2 \right)^2 + \left( y_A + L \sin \psi - y_2 \right)^2 = r^2 \tag{2'}
\end{align*}

Now, equations (1) and (2') form a nonlinear system in $x_A, y_A$.

Once $A$ is solved, compute:
\begin{align*}
P &= A + L(\cos \psi, \sin \psi)
\end{align*}

Then, compute the angle between the \textbf{tangent direction} at the contact points and the ground (i.e., the horizontal x-axis). The tangent direction at a point on a circle is perpendicular to the radial vector from the circle's center to that point.

Let the centers of the circles be $C_1 = (x_1, y_1)$ and $C_2 = (x_2, y_2)$, and the contact points be $A = (x_A, y_A)$ and $P = (x_P, y_P)$. The radial vectors are:

\[
\vec{n}_1 = A - C_1 = (x_A - x_1,\ y_A - y_1), \quad
\vec{n}_2 = P - C_2 = (x_P - x_2,\ y_P - y_2)
\]

The corresponding tangent vectors (obtained by rotating the radial vectors 90° clockwise) are:

\[
\vec{t}_1 = (-(y_A - y_1),\ x_A - x_1), \quad
\vec{t}_2 = (-(y_P - y_2),\ x_P - x_2)
\]

The angles between the tangent vectors at the contact points and the ground (horizontal axis) are given by:

\[
\theta_1 = \mathrm{mod}\left( \arctan2(t_{1,y},\ t_{1,x}),\ 2\pi \right)
\]
\[
\theta_2 = \mathrm{mod}\left( \arctan2(t_{2,y},\ t_{2,x}),\ 2\pi \right)
\]

These angles represent the \textbf{oriented direction} of the tangents relative to the ground, measured counterclockwise from the positive \(x\)-axis and wrapped into the interval \([0,\ 2\pi)\).

\subsubsection*{Case2}

\indent \indent For case 2, we can express that tangent line for robot body reachability circle
at point B also must tanget with \(c_2\). Therefore we can formulate:
\begin{align*}
    &\text{Let } \vec{n} := B - A \\
    &\text{Define a line } \ell \text{ such that:} \\
    &\quad B \in \ell,\quad \vec{d}_\ell \cdot \vec{n} = 0 \quad \text{i.e., }\ell \text{ is tangent to } c_A \text{ at } B \\
    &\quad \exists\ P' \in \ell \cap \partial c_2,\quad \vec{d}_\ell \cdot (P' - C_2) = 0 \quad \text{i.e., } \ell \text{ is tangent to } c_2 \text{ at } P'\\
    &\quad \abs{BP'} \leq \abs{BP}
\end{align*}

\begin{note}
    For Case2, the pitch angle \(\beta\) does not matter and we can still find at most one solution.
\end{note}

Let $\vec{d}_\ell$ be the direction vector of $\ell$, defined by:
\begin{align*}
    \vec{d}_\ell &= (-n_y,\ n_x) \quad \text{(perpendicular to } \vec{n} = B - A\text{)}
\end{align*}

Then, the parametric equation of $\ell$ is:
\begin{align*}
    \ell(\lambda) &= B + \lambda \vec{d}_\ell
\end{align*}

To ensure tangency with $c_2$, we require:
\begin{align*}
    \|\ell(\lambda) - C_2\|^2 &= r^2
\end{align*}
which leads to a quadratic in $\lambda$:
\begin{align*}
    \|B + \lambda \vec{d}_\ell - C_2\|^2 &= r^2
\end{align*}

Solving this yields candidate point(s) $P' = B + \lambda^* \vec{d}_\ell$.
Select the point that satisfies:
\begin{align*}
    \|BP'\| &\leq \|BP\|
\end{align*}

Finally, the center $A$ of $c_A$ is obtained by inverting $\vec{n}$:
\begin{align*}
    \vec{n}_{\text{unit}} &= \frac{\vec{n}}{\|\vec{n}\|} \\
    A &= B - R \cdot \vec{n}_{\text{unit}}
\end{align*}

This determines $A$ and $P'$ geometrically under the tangency constraints.

\newpage
\section{From d'Alembert principle to Dynamics}
The d'Alembert principle provides a natural bridge from statics to dynamics. 
% It states that the dynamics of a mechanical system can be described as a 
% generalized static equilibrium, once the inertial forces are included. 
% For a system of particles, the principle is written as:

\begin{theorem}\label{thm:ld'Alembert}
    \[
    \sum_i \left( \mathbf{F}_i - m_i \mathbf{a}_i \right) \cdot \delta \mathbf{r}_i = 0
    \]
\end{theorem}

where $\mathbf{F}_i$ is the applied force on the $i$-th particle, $m_i \mathbf{a}_i$ is its inertial force, and $\delta \mathbf{r}_i$ denotes any virtual displacement compatible with the system's constraints.

Let the position of the robot's center of mass be denoted by \( \mathbf{r}_G^\mathcal{I} \in \mathbb{R}^2 \). And two leg contact position
as \( \mathbf{p}_A^\mathcal{I} \)  and \( \mathbf{p}_B^\mathcal{I} \).

\subsection{Holonomic constraints:}

Using the identity \( \sin(\arctan(x)) = \frac{x}{\sqrt{1 + x^2}} \), the geometric constraint imposed by the spine length can be rewritten as:

\[
L_\text{Arm} = \left\| \mathbf{p}_B^\mathcal{I} - \mathbf{p}_A^\mathcal{I} \right\| =
\frac{L_\text{Spine}^2}{\sqrt{L_\text{Spine}^2 + \left(L_{\text{Leg}2} - L_{\text{Leg}1}\right)^2}}
\]

The terrain contact constraints are then written as:

\[
f_A := p_{A,y}^\mathcal{I} - h(p_{A,x}^\mathcal{I}) = 0, \quad
f_B := p_{B,y}^\mathcal{I} - h(p_{B,x}^\mathcal{I}) = 0
\]

In general, the center of mass can be written as a function of the two foot positions \( \mathbf{p}_A^\mathcal{I} \) and \( \mathbf{p}_B^\mathcal{I} \), depending on the mass distribution and geometry:

\[
\mathbf{r}_G^\mathcal{I} = \mathbf{f}_G\left( \mathbf{p}_A^\mathcal{I}, \mathbf{p}_B^\mathcal{I} , \beta \right)
\]
where \( \beta \) is the pitch angle of the spine, measured from horizontal and it can be derived through
\(\mathbf{f}_{\beta}(\mathbf{p}_A^\mathcal{I},\mathbf{p}_B^\mathcal{I},L_\text{Spine},L_{\text{Leg}1},L_{\text{Leg}2})\) 
by geometric constrains following:
\begin{enumerate}
    \item $\|\mathbf{q}_1 - \mathbf{p}_A\| = L_\text{Leg1}$
    \item $\|\mathbf{q}_2 - \mathbf{p}_B\| = L_\text{Leg2}$
    \item $\|\mathbf{q}_2 - \mathbf{q}_1\| = L_\text{Spine}$
    \item Directional constraint: 
    \[
        \mathbf{q}_1 - \mathbf{p}_A \parallel \mathbf{q}_2 - \mathbf{p}_B 
        \Rightarrow 
        (\mathbf{q}_1 - \mathbf{p}_A) = \lambda (\mathbf{q}_2 - \mathbf{p}_B)
    \]
\end{enumerate}
Therefore, we get:
\begin{align*}
& (x_1 - x_A)^2 + (y_1 - y_A)^2 = L_{\text{Leg}1}^2 \\[0.5em]
& (x_2 - x_B)^2 + (y_2 - y_B)^2 = L_{\text{Leg}2}^2 \\[0.5em]
& (x_2 - x_1)^2 + (y_2 - y_1)^2 = L_{\text{Spine}}^2 \\[0.5em]
& (x_1 - x_A)(y_2 - y_B) - (y_1 - y_A)(x_2 - x_B) = 0
\end{align*}

And therefore, we can get the solution of \(x_1, x_2, y_1, y_2\) through numerical method. 
And then, we can find the \(\beta\) by: 
\[
\beta = \operatorname{atan2}\!\bigl(y_1 - y_A,\; x_1 - x_A\bigr) \\[6pt]
\]  

Furthure more, we can even determine the \textbf{CoM} by: 
\[
\mathbf{r}_G^\mathcal{I} =
\begin{bmatrix}
x_m \\
y_m
\end{bmatrix}
+
d \begin{bmatrix}
\cos\beta \\
\sin\beta
\end{bmatrix},
\quad
\text{where} \quad
\begin{bmatrix}
x_m \\
y_m
\end{bmatrix}
=
\frac{1}{2}
\begin{bmatrix}
x_1 + x_2 \\
y_1 + y_2
\end{bmatrix},
\text{and } d 
\text{ is offset} 
\]

\subsection{Non-Holonomic constraints:}
\indent \indent There are none.

\vspace{10pt}
Therefore, the total \textbf{DoF} is \(3N-5 =1\). This indicates we can desribe the whole system through one generalized
coordinate. And we can choose \(x_{A}^{\mathcal{I}}\) for simplicity. We can describe as \( q := x_A^\mathcal{I} \). All other quantities can be written as functions of \( q \) due to the holonomic constraints.
\[
\mathbf{p^\mathcal{I}}_A(q) =
\begin{bmatrix}
q \\
h(q)
\end{bmatrix}, \quad
\mathbf{p^\mathcal{I}}_B(q) =
\begin{bmatrix}
\mathbf{f}_B(q) \\
h(\mathbf{f}_B(q))
\end{bmatrix}, \quad
\mathbf{r}_G^\mathcal{I} =
\begin{bmatrix}
\mathbf{f}_{Gx}(q) \\
\mathbf{f}_{Gy}(q)
\end{bmatrix}
\]

Then, the velocity and acceleration of the \textbf{CoM} can be expressed as:
\[
\dot{\mathbf{r}}_G = \frac{d \mathbf{f}_G}{dq} \cdot \dot{q}, \quad
\ddot{\mathbf{r}}_G = \frac{d \mathbf{f}_G}{dq} \cdot \ddot{q} + \frac{d^2 \mathbf{f}_G}{dq^2} \cdot \dot{q}^2
\]

Therefore, through d'Alembert principle, we write:
\[
\left(\mathbf{f}_A + \mathbf{f}_B 
+ \mathbf{F}_g 
- m\ddot{\mathbf{r}}_G \right) 
\cdot \delta \mathbf{r}_G = 0
\]

\subsection{Sinusoidal Terrain}
\indent \indent Lets start with the sinusoidal terrain where the terrain is easy to express with one function:

\[
h(x^\mathcal{I}) = A \cdot \sin\left( \frac{2\pi}{T} x^\mathcal{I} + \phi \right) + B
\]

We can set \(B\) as \(\frac{A}{2}\) and \(\theta\) as 0 and gives us: 

\[
h(x^\mathcal{I}) = A \cdot \sin\left( \frac{2\pi}{T} x^\mathcal{I} \right) + \frac{A}{2}
\]

Therefore, we can express our three key points explicitly as:

\[
\footnotesize
\setlength{\arraycolsep}{6pt}   % space between columns
\renewcommand{\arraystretch}{1.05}% vertical row spacing
\begin{array}{@{}l@{\qquad}l@{}}
%%%%%%%%%%%%%%%%%%%%%%%%%%%%%%%%%%%%%%%%%%%%%%%%%%%%%%%%%%%%
\mathbf{p}_A^\mathcal{I}(q)=
\begin{bmatrix}
q\\
A\sin\!\bigl(\tfrac{2\pi}{T}q\bigr)+\tfrac{A}{2}
\end{bmatrix}
&
\text{directly defined by } q
\\[.8em]
\noalign{\hrule height 0.35pt}
%%%%%%%%%%%%%%%%%%%%%%%%%%%%%%%%%%%%%%%%%%%%%%%%%%%%%%%%%%%%
\mathbf{p}_B^\mathcal{I}(q)=
\begin{bmatrix}
x_B(q)\\
A\sin\!\bigl(\tfrac{2\pi}{T}x_B(q)\bigr)+\tfrac{A}{2}
\end{bmatrix}
&
\begin{aligned}
x_B(q)\ \text{solves:}\quad
(x_B-q)^2
&+\Bigl[A\sin\!\bigl(\tfrac{2\pi}{T}x_B\bigr)
      -A\sin\!\bigl(\tfrac{2\pi}{T}q\bigr)\Bigr]^2
      =L_{\text{Arm}}^{\,2}
\end{aligned}
\\[.8em]
\noalign{\hrule height 0.35pt}
%%%%%%%%%%%%%%%%%%%%%%%%%%%%%%%%%%%%%%%%%%%%%%%%%%%%%%%%%%%%
\mathbf{r}_G^\mathcal{I}(q)=
\begin{bmatrix}
x_m\\
y_m
\end{bmatrix}
+
d\!
\begin{bmatrix}
\cos\beta\\
\sin\beta
\end{bmatrix}
&
\begin{aligned}
x_m &=\tfrac12(x_1+x_2),\quad
y_m=\tfrac12(y_1+y_2)\\[2pt]
\beta &=\operatorname{atan2}(y_1-y_A,\;x_1-x_A)\\[4pt]
x_1, x_2, y_1, y_2\ \text{solves:}\quad
(x_1-x_A)^2+(y_1-y_A)^2 &=L_{\text{Leg}1}^2\\
(x_2-x_B)^2+(y_2-y_B)^2 &=L_{\text{Leg}2}^2\\
(x_2-x_1)^2+(y_2-y_1)^2 &=L_{\text{Spine}}^2\\
(x_1-x_A)(y_2-y_B) -\,(y_1-y_A)(x_2-x_B)&=0
\end{aligned}
\end{array}
\]

Therefore, we can now expand out the equation for virtual work as follows:

\[
\left(
\mathbf{f}_A \cdot \frac{d\mathbf{p}_A}{dq}
+ \mathbf{f}_B \cdot \frac{d\mathbf{p}_B}{dq}
+ \mathbf{F}_g \cdot \frac{d\mathbf{r}_G}{dq}
- m \ddot{\mathbf{r}}_G \cdot \frac{d\mathbf{r}_G}{dq}
\right)
\delta q = 0
\]

\[
\begin{aligned}
\mathbf{f}_A &= 
\lambda_N^A \, \hat{\mathbf{n}}_A +
\lambda_f^A \, \hat{\mathbf{t}}_A +
\lambda_{\parallel}^A \, \hat{\mathbf{e}}_\beta +
\lambda_{\perp}^A \, \hat{\mathbf{e}}_\beta^\perp \\[0.5em]
\mathbf{f}_B &= 
\lambda_N^B \, \hat{\mathbf{n}}_B +
\lambda_f^B \, \hat{\mathbf{t}}_B +
\lambda_{\parallel}^B \, \hat{\mathbf{e}}_\beta +
\lambda_{\perp}^B \, \hat{\mathbf{e}}_\beta^\perp
\end{aligned}
\]

where we can expand out as:
\[
\begin{aligned}
&\Big(
\underbrace{
\lambda_N^A \, \hat{\mathbf{n}}_A \cdot \frac{d\mathbf{p}_A}{dq}
+ \lambda_f^A \, \hat{\mathbf{t}}_A \cdot \frac{d\mathbf{p}_A}{dq}
+ \lambda_{\parallel}^A \, \hat{\mathbf{e}}_\beta \cdot \frac{d\mathbf{p}_A}{dq}
+ \lambda_{\perp}^A \, \hat{\mathbf{e}}_\beta^\perp \cdot \frac{d\mathbf{p}_A}{dq}
}_{\mathbf{f}_A \cdot \frac{d\mathbf{p}_A}{dq}} \\[0.8em]
&\quad
+ \underbrace{
\lambda_N^B \, \hat{\mathbf{n}}_B \cdot \frac{d\mathbf{p}_B}{dq}
+ \lambda_f^B \, \hat{\mathbf{t}}_B \cdot \frac{d\mathbf{p}_B}{dq}
+ \lambda_{\parallel}^B \, \hat{\mathbf{e}}_\beta \cdot \frac{d\mathbf{p}_B}{dq}
+ \lambda_{\perp}^B \, \hat{\mathbf{e}}_\beta^\perp \cdot \frac{d\mathbf{p}_B}{dq}
}_{\mathbf{f}_B \cdot \frac{d\mathbf{p}_B}{dq}} \\[0.8em]
&\quad
+ \mathbf{F}_g \cdot \frac{d\mathbf{r}_G}{dq}
- m \ddot{\mathbf{r}}_G \cdot \frac{d\mathbf{r}_G}{dq}
\Big) \delta q = 0
\end{aligned}
\]

\begin{itemize}
  \item[1.] \( \lambda_N^A \, \hat{\mathbf{n}}_A \cdot \frac{d\mathbf{p}_A}{dq} = 0 \)  
        (Normal force is perpendicular to virtual displacement: does no work)

  \item[2.] \( \lambda_f^A \, \hat{\mathbf{t}}_A \cdot \frac{d\mathbf{p}_A}{dq}
  = \lambda_f^A \cdot \left\| \frac{d\mathbf{p}_A}{dq} \right\| \),  
  because \( \hat{\mathbf{t}}_A \parallel \frac{d\mathbf{p}_A}{dq} \)

  \item[3.] \( \left( \lambda_{\parallel}^A \cdot \frac{d\mathbf{p}_A}{dq}
    + \lambda_{\parallel}^B \cdot \frac{d\mathbf{p}_B}{dq} \right)
    \cdot \hat{\mathbf{e}}_\beta \)  
    (Combined contribution of spine-direction forces at A and B)

  \item[4.] \( \left( \lambda_{\perp}^A \cdot \frac{d\mathbf{p}_A}{dq}
    + \lambda_{\perp}^B \cdot \frac{d\mathbf{p}_B}{dq} \right)
    \cdot \hat{\mathbf{e}}_\beta^\perp \)  
    (Combined contribution of perpendicular forces along the direction orthogonal to the spine)

    \item[5.]  % ——B-point friction term
    \[
    \boxed{
    \hat{\mathbf{t}}_B =
    \frac{1}{\sqrt{1 + \left( h'(x_B) \right)^2}}
    \begin{bmatrix}
    1 \\
    h'(x_B)
    \end{bmatrix}
    }, \qquad
    \boxed{
    \hat{\mathbf{n}}_B =
    \frac{1}{\sqrt{1 + \left( h'(x_B) \right)^2}}
    \begin{bmatrix}
    - h'(x_B) \\
    1
    \end{bmatrix}
    }.
    \]
\end{itemize}

\newpage
\subsection{Zig-Zag Terrain}
The zig-zag terrain is defined by a periodic piecewise function \( y = h(x^\mathcal{I}) \), with period \( T = 2r + d \) and height \( h = r \tan\theta \). For each point \( x^\mathcal{I} \in \mathbb{R} \), define \( x_k = x^\mathcal{I} \bmod T \). Then:

\[
h(x^\mathcal{I}) =
\begin{cases}
\tan\theta \cdot x_k, & x_k \in [0, r] \\
\tan\theta \cdot (2r - x_k), & x_k \in [r, 2r] \\
0, & x_k \in [2r, 2r + d]
\end{cases}
\]

Here, in order to make the terrain differentiable at any point, we can use fourier series to approximate the terrain like:

\[
h(x^\mathcal{I}) = \frac{8 r \tan\theta}{\pi^2} \sum_{n=1,3,5,\dots}^{N} \frac{1}{n^2} \cos\left( \frac{2\pi n x}{2r + d} \right)
\]

% \subsection*{Cylinder Terrain}
% Lets firstly parameterize our target terrain as:
% \[
% y = 
% \begin{cases}
% 0, & x_0 + (a + 2r)k \leq x \leq x_0 + (a + 2r)k + a \\
% \sqrt{r^2 - (x - (a + r))^2}, & x_0 + (a + 2r)k + a \leq x \leq x_0 + (a + 2r)k + a + 2r
% \end{cases}
% \]

% \noindent
% where \( a \) is the gap distance between curved segments, and \( x_0 \) is the initial offset.

\newpage
\subsection{Dynamics}
\indent

Generalized coordinate: \(p_A^x, l_1, l_2, l_3\)

terrain function: \(h(x)\)

\(p_B^x: (p_B^x - p_B^x)^2 + (h(p_B^x) - h(p_B^x))^2 = \frac{l_2^4}{l_2^2+(l_3^2 - l_1^2)^2}\)

\(\beta: \beta = \arcsin(\frac{(p_B^x+\cos(\beta) \cdot l_3) - (p_A^x+\cos(\beta) \cdot l_1)}{l_2})\)

\(\mathbf{r_{com}} = \)

\end{document}

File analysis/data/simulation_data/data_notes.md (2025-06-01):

1. trajectory_log_com1
flat_groud
Shaft Length: Fixed to 0cm, only moved the two pairs of leg in phase, aim to see how leg movement affect the com

2. trajectory_log_com2
flat_groud
Shaft Length: Fixed to 9cm, only moved the two pairs of leg in phase, aim to see how leg movement affect the com

3. trajectory_log_com3
flat_groud
Shaft Length: varied shaft length from 1cm to 9cm with step size 1, aim to see how spine length affect the change of com during leg movement

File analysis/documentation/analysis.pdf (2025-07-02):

## Force Based Model Analysis

Jerry Wu

July 1, 2025

Helpful Link:

- Geogebra Demo (https://www.geogebra.org/classic/vzgc97bq)
- Canva Graphics (https://www.canva.com/design/DAGo-OCr6Yo/K5YV57vaBxux-PqkqwI4ow/edit)

Assumption 0.1. The robot body would never contact with the terrain

Assumption 0.2. The CoM of the robot is always at local geometric center in direction parrallel to Spine

## 1 Statics

Assumption 1.1. Static means the robot would not move and achieve static equilibrium in this state

Slope

Diagram 1.2. Simple case where two legs have same height


To start with, we put robot on a slope with angle θ. To make the analysis easier, assume that two leg have same height h in this case. Therefore, the moment arm are symetric for RA and RB. Therefore, we can get follow equations:

XFx = (f1 + f2) − sin(θ)mg = 0

XFy = (NA + NB) − cos(θ)mg = 0

XMA = Lspine · NB − L · mg · sinπ
2

− ϕ + θ

= 0

XMB = Lspine · NA − L · mg · sinπ 2

− ϕ + θ

= 0

Diagram 1.3. Two legs have different height


Now extend the case to where the leg length would change. Here the robot extended the right leg to h2, which makes the robot rotate angle β around the z-Axis. Now both moment arms on two legs are shifted. We can also form the static equilibrium equation as follows:

XFx = (f1 + f2) − sin(θ)mg = 0

XFy = (NA + NB) − cos(θ)mg = 0

XMA =

Lspine
sin

π
2 − β

· NB · sinπ
2

− L1 · mg · sinπ
2

− ϕ1 + θ

= 0

XMB =

Lspine
sin

π
2 − β

· NA · sinπ
2

− L2 · mg · sinπ
2

− ϕ2 − θ

= 0

based on the geometry of our robot, we can also formulate:

Lspine · cosπ
2

− β

= h2 − h1

Note 1.4. h1, h2 are known values, so β is also known. Therefore, ϕ1 and ϕ2 can easily be solved using Theorem 1.5.

Theorem 1.5. Law of Cosines

cos A =

b

2 + c

2 − a

2

2bc

cos B =

a

2 + c

2 − b

2

2ac

cos C =

a

2 + b

2 − c

2

2ab

Zig-Zag Terrain

Assumption 1.6. The terrain is uniform that all triangle obstable and gap between them are same

A natural extension for the slope is triangle terrain. There are esseintially five cases when robot is static on the triangle terrain: 1. two legs on the same slope 2. two legs on two slopes that face each other 3. two legs on two slopes that does not face each other 4. one leg is on the slope and the other is on the gap. 5. two legs are all on the gap.
For case 1, we have already discussed in the previous section. And for case 5, it is esseintially the same like slope when θ is 0.

Diagram 1.7. Case2: two legs on the slope that face each other


To make it clearer, I changed the coordinate that aligns with the ground rather slope from now on. We can also formulate the equilibrium equations:

XFx = (−f1 + f2) cos(θ) + (NA − NB) sin(θ) = 0

XFy = (f1 + f2) sin(θ) + (NA + NB) cos(θ) − mg = 0

XMA = LArm · (NB · sinπ
2

− ω2

+ f2 · sin(π − ω2)) − L1 · mg · sin(µ1) = 0

XMB = LArm · (NB · sinπ
2

− ω1

+ f1 · sin(π − ω1)) − L2 · mg · sin(µ2) = 0

where by geometry of the shape, we can find:

ω1 = (θ + β) − (

π
2

− α)

ω2 = (θ − β) + (π
2

− α)

µ1 = π − (ϕ1 + ω1) − (

π
2

− θ)

µ2 = π − (ϕ2 + ω2) − (

π
2

− θ)

α = arctan
LSpine
h2 − h1

LArm = sin(α) · LSpine

similarly to Note 1.4, this equalion can be solved.

Diagram 1.8. Case3: two legs on two slopes that do not face each other


XFx = (f1 − f2) cos(θ) + (−NA + NB) sin(θ) = 0

XFy = (f1 − f2) sin(θ) + (−NA + NB) cos(θ) − mg = 0

XMA = LArm · (NB · sin(π − ω2) + f2 · sinπ 2

− ω2

) − L1 · mg · sin(µ1) = 0

XMB = LArm · (NA · sin(π − ω1) + f1 · sinπ 2

− ω1

) − L2 · mg · sin(µ2) = 0

where by geometry of the shape, we can find:

ω1 = β + α − θ

ω2 = π − β − α − θ

µ1 = π − (ϕ1 + ω1) − θ

µ2 = π − (ϕ2 + ω2) − θ

α = arctan
LSpine
h2 − h1

LArm = sin(α) · LSpine

Note 1.9. The equation for ω1 can be found specifically by following equation:

x1 + ϕ1 + ω1 + θ = π | (1)

β + x1 + ϕ1 −

π
2

− α

=

π
2

(2)

ω1 = β + α − θ | From (1) and (2)

Diagram 1.10. Case4: one leg is on the slope and the other is on the gap


XFx = −f1 cos(θ) − f2 + NA sin(θ) = 0

XFy = f1 sin(θ) + NA cos(θ) + NB − mg = 0

XMA = LArm · (NB · sin(π − ω2) + f2 · sinπ 2

− ω2

) − L1 · mg · sin(µ1) = 0

XMB = LArm · (NB · sin(π − ω1) + f1 · sin 3π
2

− ω1

) − L2 · mg · sin(µ2) = 0

where by geometry of the shape, we can find:

ω1 = θ − β + α

ω2 = π + β − α

µ1 = π − (ϕ1 + ω1) − θ

µ2 = π − (ϕ2 + ω2)

α = arctan
LSpine
h2 − h1

LArm = sin(α) · LSpine

Note 1.11. The equation for ω1 can be found specifically by following equation:

x1 + ϕ1 + ω1 = π | (3)

θ − β + x1 + ϕ1 −

π
2

− α

=

π
2

(4)

ω1 = θ − β + α | From (1) and (2)

Now, by observation, this case is very similar to previous case. In fact, all of the above cases are geometrically similar, which means we can find a general expression for this force based model.

Diagram 1.12. Determine the geometry shape by robot body and terrain


After simplifying the model, it can be seen that given the terrain tangent angle θ1, θ2, robot pitch angle β and length of the virtual link between end point of two leg LArm we can determine the triangle with inner angle a, b, c.
Here is how we determine angle a, b, c:

a = π − θ1 − θ2

b = π − β −

π
2

− (

π
2

− αL) − (π − θ1)

c = π − (π − θ2) + β − αL

by verification:
a + b + c = π

As for different tangent angles, this property should hold as well. This means there would be

only one solution by given condition.

Diagram 1.13. Generailized Free Body Diagram


Given the determined geometric shape of the robot and terrain, we can easily find the position of the COM through the given of relative position L1 and L2, which can be solved by the geometry as well. Which means, if we put the robot into coordinate, the points (XA, YA),(XB, YB),(XCOM , YCOM )

are given.
Therefore, given (XA, YA),(XB, YB),(XCOM , YCOM ), θ1, θ2, LSpine we can formulate

XF⃗ = ⃗f1 + ⃗f2 + N⃗A + N⃗B + W⃗ = ⃗0

XM⃗ A = (⃗rB − ⃗rA) × (
⃗f2 + N⃗B) + (⃗rCOM − ⃗rA) × W⃗ = 0

XM⃗ B = (⃗rA − ⃗rB) × (
⃗f1 + N⃗A) + (⃗rCOM − ⃗rB) × W⃗ = 0

where

tˆ1 = (cos(π − θ1), sin(π − θ1)) (contact tangent 1)

nˆ1 = (− sin(π − θ1), cos(π − θ1)) (contact normal 1)

tˆ2 = (cos θ2, sin θ2)

nˆ2 = (− sin θ2, cos θ2)

⃗f1 = f1 · tˆ1 = f1 · (cos(π − θ1), sin(π − θ1))

N⃗A = NA · nˆ1 = NA · (− sin(π − θ1), cos(π − θ1))

⃗f2 = f2 · tˆ2 = f2 · (cos θ2, sin θ2)

N⃗B = NB · nˆ2 = NB · (− sin θ2, cos θ2)

W⃗ = −mg · (0, 1)

Moment arm of ⃗f2, N⃗B about A : ⃗rf2/A = ⃗rB − ⃗rA = (XB − XA, YB − YA)

Moment arm of W⃗ about A : ⃗rW/A = ⃗rCOM − ⃗rA = (XCOM − XA, YCOM − YA)

Moment arm of ⃗f1, N⃗A about B : ⃗rf1/B = ⃗rA − ⃗rB = (XA − XB, YA − YB)

Moment arm of W⃗ about B : ⃗rW/B = ⃗rCOM − ⃗rB = (XCOM − XB, YCOM − YB)

Therefore,
XF⃗
x = −f1 cos θ1 + f2 cos θ2 − NA sin θ1 − NB sin θ2 = 0
XF⃗
y = f1 sin θ1 + f2 sin θ2 − NA cos θ1 + NB cos θ2 − mg = 0

XM⃗ A = (XB − XA)(f2 sin θ2 + NB cos θ2) − (YB − YA)(f2 cos θ2 − NB sin θ2) − mg(XCOM − XA) = 0

XM⃗ B = (XA − XB)(f1 sin θ1 − NA cos θ1) − (YA − YB)(−f1 cos θ1 − NA sin θ1) − mg(XCOM − XB) = 0

solve,

NA =

gm(XB − XCOM) cos θ1
XA − XB

NB =

gm(XA − XCOM) cos θ2
XA − XB

f1 =

gm(XCOM − XB) sin θ1
XA − XB

f2 =

gm(XA − XCOM) sin θ2
XA − XB

By friction function |f| ≤ µN, we can solve this equation and find

|f1| =

gm(XCOM − XB) sin θ1
XA − XB

≤ µ ·

gm(XB − XCOM) cos θ1
XA − XB

= µNA

|f2| =

gm(XA − XCOM) sin θ2
XA − XB

≤ µ ·

gm(XA − XCOM) cos θ2
XA − XB

= µNB

The above expression is derived in case where the θ1 and θ2 are both acute angles from graphic definition, but it is clear that in other cases, they are the same, a even more genral expression is actually:

⃗f1 = f1 · tˆ1

N⃗A = NA · nˆ1

⃗f2 = f2 · tˆ2

N⃗B = NB · nˆ2

W⃗ = −mg · (0, 1)

XFx = f1t1x + f2t2x + NAn1x + NBn2x = 0

XFy = f1t1y + f2t2y + NAn1y + NBn2y − mg = 0

XMA = (xB − xA)(f2t2y + NBn2y) − (yB − yA)(f2t2x + NBn2x)

− mg(xCOM − xA) = 0

XMB = (xA − xB)(f1t1y + NAn1y) − (yA − yB)(f1t1x + NAn1x)

− mg(xCOM − xB) = 0

In matrix form:
t1x | t2x | n1x | n2x
t1y | t2y | n1y | n2y
0 | ∆xBAt2y − ∆yBAt2x | 0 | ∆xBAn2y − ∆yBAn2x
∆xABt1y − ∆yABt1x | 0 | ∆xABn1y − ∆yABn1x | 0

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
mg(xCOM − xA)
mg(xCOM − xB)

Friction Cone Constraints

⃗f1| ≤ µ|NA|, |

⃗f2| ≤ µ|NB|

Cylinder Terrain

Diagram 1.14. Generailized expression on Cylinder Terrain


With the general expression, we can directly put the same graph within in a cylinder terrian, where θ1 and θ2 are esseintially the tangent line with the cylinder.

Diagram 1.15. Impossible case under Assumption ??


However, here, it is impossible that right leg is still contacting the ground due to β. In this case, the generalized geometric is not applied completely, which requires furthur discuss by changing the assumption ??.
However, this case can also be determined geometrically. Now let’s firstly simplify the problem that all cylinder shape on this terrain has same radius.

Cylinder Terrain when radius are identical

I made a simple demo for robot geometric shape can be found in this GeoGebra link. (https://www.geogebra.org/classic/vzgc97bq) Here A represents the contact point of left leg on the left circle and AB represents of LSpine. The moving P point represents the right leg extension and AP represents the LArm.For both folowing cases, we form equations as follows in coordinates:

Note 1.16. In this terrain, what we actually want to consider is given the shape of the cylinder (i.e radius and gap), how can we find the θ1 and θ2.

Diagram 1.17. When Point P contacts the terrain


Diagram 1.18. When Segment tangents the terrain


Obstacle and Terrain Representation

Obstacle c1 | (x − c1)

2 + y

2 = r

2

Obstacle c2 | (x − c2)

2 + y

2 = r

2

Control Parameters

θ ∈ [0, π] | (defines point A on the upper half of the circle centered at c1)
φ ∈ [0, 2π] | (controls the direction of the robot spine extended from point A)
s ∈ [−Lleg, 0] | (represents the extension length of the right leg from point B)

Point Definitions

A = (x0, y0) = (c1 + r cos θ, r sin θ)

B = (x1, y1) = (x0 + Lspine cos φ, y0 + Lspine sin φ)

Body Reachability Circle

cA : (x − x0)

2 + (y − y0)

2 = L

2
Spine

Direction Vector and Point P

⃗t = (tx, ty) = (− sin φ, cos φ)

P = (xP , yP ) = (x1 + stx, y1 + sty)

Collision Condition Generally speaking, segment BP must intersect the boundary of Obstacle 2 exactly once:

BP ∩ ∂c2
= 1

BP ∩ c

◦
2 = ∅

Case1

In this case, it is very similar to what we did in the previous sections that we would consider pitch angle β in consideration. With that, we can determine triangle with knowning that A and P

are on c1 and c2 and their angle.

Diagram 1.19. Determine the geometric shape


- Two circles c1 and c2 with centers C1 = (x1, y1) and C2 = (x2, y2) respectively, both of radius

r.

- Unknown points A ∈ ∂c1, P ∈ ∂c2.
- Length L = ∥A − P∥ is known.
- Direction angle of AP⃗ is known: ψ ∈ [0, 2π] from pitch angle β.

Note 1.20. To be more specific, direction angle is derived from both the geometric angle formed by triangle ABP and β .

Then the direction vector is:
⃗d = AP⃗ = L(cos ψ,sin ψ)

We parameterize:

A = (xA, yA)

P = A + ⃗d = (xA + Lcos ψ, yA + Lsin ψ)

Apply the circle constraints:

∥A − C1∥

2 = r

2
(1)

∥P − C2∥

2 = r

2
(2)

Substituting into (2):

(xA + Lcos ψ − x2)

2 + (yA + Lsin ψ − y2)

2 = r
2
(2’)

Now, equations (1) and (2’) form a nonlinear system in xA, yA.

Once A is solved, compute:

P = A + L(cos ψ,sin ψ)

Then, compute the angle between the tangent direction at the contact points and the ground (i.e., the horizontal x-axis). The tangent direction at a point on a circle is perpendicular to the

radial vector from the circle’s center to that point.
Let the centers of the circles be C1 = (x1, y1) and C2 = (x2, y2), and the contact points be A = (xA, yA) and P = (xP , yP ). The radial vectors are:

⃗n1 = A − C1 = (xA − x1, yA − y1), ⃗n2 = P − C2 = (xP − x2, yP − y2)

The corresponding tangent vectors (obtained by rotating the radial vectors 90° clockwise) are:

⃗t1 = (−(yA − y1), xA − x1), ⃗t2 = (−(yP − y2), xP − x2)

The angles between the tangent vectors at the contact points and the ground (horizontal axis)

are given by:

θ1 = mod (arctan 2(t1,y, t1,x), 2π)

θ2 = mod (arctan 2(t2,y, t2,x), 2π)

These angles represent the oriented direction of the tangents relative to the ground, measured counterclockwise from the positive x-axis and wrapped into the interval [0, 2π).

Case2

For case 2, we can express that tangent line for robot body reachability circle at point B also must tanget with c2. Therefore we can formulate:

Let ⃗n := B − A

Define a line ℓ such that: B ∈ ℓ, ⃗dℓ
- ⃗n = 0 i.e., ℓ is tangent to cA at B

∃ P

′ ∈ ℓ ∩ ∂c2,

⃗dℓ
- (P

′ − C2) = 0 i.e., ℓ is tangent to c2 at P

′

BP′
≤ |BP|

Note 1.21. For Case2, the pitch angle β does not matter and we can still find at most one solution.

Let ⃗dℓ be the direction vector of ℓ, defined by:

⃗dℓ = (−ny, nx) (perpendicular to ⃗n = B − A)

Then, the parametric equation of ℓ is:

ℓ(λ) = B + λ⃗dℓ

To ensure tangency with c2, we require:

∥ℓ(λ) − C2∥

2 = r

2

which leads to a quadratic in λ:

∥B + λ⃗dℓ − C2∥
2 = r

2

Solving this yields candidate point(s) P

′ = B + λ

∗ ⃗dℓ
. Select the point that satisfies:

∥BP′
∥ ≤ ∥BP∥

Finally, the center A of cA is obtained by inverting ⃗n:

⃗nunit =

⃗n
∥⃗n∥

A = B − R · ⃗nunit

This determines A and P

′ geometrically under the tangency constraints.

## 2 From d’Alembert principle to Dynamics

The d’Alembert principle provides a natural bridge from statics to dynamics.

Theorem 2.1.
X

i

(Fi − miai) · δri = 0

where Fi

is the applied force on the i-th particle, miai is its inertial force, and δri denotes any virtual displacement compatible with the system’s constraints.
Let the position of the robot’s center of mass be denoted by r

I
G ∈ R

2
. And two leg contact

position as p

I
A

and p

I
B

### 2.1 Holonomic constraints:

Using the identity sin(arctan(x)) = √ x
1+x²

, the geometric constraint imposed by the spine length can be rewritten as:

LArm =

p

I
B − p

I
A

=

L

2
Spine
q
L

2
Spine + (LLeg2 − LLeg1)

2

The terrain contact constraints are then written as:

fA := p

I
A,y − h(p

I

A,x) = 0, fB := p I
B,y − h(p

I
B,x) = 0

In general, the center of mass can be written as a function of the two foot positions p

I
A

and p

I
B

,
depending on the mass distribution and geometry:

r

I
G = fG
p
| I
| A, p I B, β

where β is the pitch angle of the spine, measured from horizontal and it can be derived through fβ(p

I
A

, p

I
B

, LSpine, LLeg1, LLeg2) by geometric constrains following:

1. ∥q1 − pA∥ = LLeg1
2. ∥q2 − pB∥ = LLeg2
3. ∥q2 − q1∥ = LSpine
4. Directional constraint:

q1 − pA ∥ q2 − pB ⇒ (q1 − pA) = λ(q2 − pB)

Therefore, we get:

(x1 − xA)

2 + (y1 − yA)

2 = L

2
Leg1

(x2 − xB)

2 + (y2 − yB)

2 = L

2
Leg2

(x2 − x1)

2 + (y2 − y1)

2 = L

2
Spine

(x1 − xA)(y2 − yB) − (y1 − yA)(x2 − xB) = 0

And therefore, we can get the solution of x1, x2, y1, y2 through numerical method. And then, we can find the β by:
β = atan2
y1 − yA, x1 − xA

Furthure more, we can even determine the CoM by:

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
cos β
sin β

, | where | "
xm
ym
=

1
2

"
x1 + x2
y1 + y2
, and d is offset

### 2.2 Non-Holonomic constraints:

There are none.

Therefore, the total DoF is 3N −5 = 1. This indicates we can desribe the whole system through

one generalized coordinate. And we can choose x

I
A

for simplicity. We can describe as q := x

I
A

. All
other quantities can be written as functions of q due to the holonomic constraints.

p

I

A(q) = "
q
h(q)
, p I

B(q) = "
fB(q)

h(fB(q))#
, r I
G =

"
fGx(q)

fGy(q)

Then, the velocity and acceleration of the CoM can be expressed as:

r˙G =

dfG
dq · q,˙ ¨rG =

dfG
dq · q¨+

d

2
fG
dq²
- q˙

2

Therefore, through d’Alembert principle, we write:

(fA + fB + Fg − m¨rG) · δrG = 0

### 2.3 Sinusoidal Terrain

Lets start with the sinusoidal terrain where the terrain is easy to express with one function:

h(x

I

) = A · sin
2π
T

x

I + ϕ

+ B

We can set B as A
2

and θ as 0 and gives us:

h(x

I

) = A · sin
2π
T

x

I

+

A
2

Therefore, we can express our three key points explicitly as:

p

I

A(q) = "
q
A sin

2π
T

q

+

A
2
directly defined by q

p

I

B(q) = "
xB(q)
A sin

2π
T

xB(q)

+

A
2
xB(q) solves: (xB − q)

2 +

h
A sin

2π
T

xB

− A sin

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
G(q) = "
xm
ym
+ d

"
cos β
sin β

xm =

1/2(x1 + x2), ym =

1/2(y1 + y2)

β = atan2(y1 − yA, x1 − xA)

x1, x2, y1, y2 solves: (x1 − xA)

2 + (y1 − yA)

2 = L

2
Leg1
(x2 − xB)

2 + (y2 − yB)

2 = L

2
Leg2
(x2 − x1)

2 + (y2 − y1)

2 = L

2
Spine
(x1 − xA)(y2 − yB) − (y1 − yA)(x2 − xB) = 0
Therefore, we can now expand out the equation for virtual work as follows:
fA ·

dpA
dq + fB ·

dpB
dq + Fg ·

drG
dq − m¨rG ·

drG

dq
δq = 0

fA = λ

A
N nˆA + λ

A
f

ˆtA + λ

A
∥

eˆβ + λ

A
⊥ eˆ

⊥
β

fB = λ

B
N nˆB + λ

B
f

ˆtB + λ

B
∥

eˆβ + λ

B
⊥ eˆ

⊥
β

where we can expand out as:
λ

A
N nˆA ·

dpA
dq + λ

A
f

ˆtA ·

dpA
dq + λ

A
∥

eˆβ ·

dpA
dq + λ

A
⊥ eˆ

⊥
β

·

dpA
dq
| | {z | }
| fA· dpA dq

+ λ

B
N nˆB ·

dpB
dq + λ

B
f

ˆtB ·

| dpB dq + λ
B
∥

eˆβ ·

dpB
dq + λ

B
⊥ eˆ

⊥
β

·

| | dpB
| | dq
| | {z | }
| fB· dpB dq

+ Fg ·

drG
dq − m¨rG ·

drG
dq
| δq = 0
1. λ

A
N nˆA ·

dpA
dq = 0 (Normal force is perpendicular to virtual displacement: does no work)
2. λ

A
f

ˆtA ·

dpA
dq = λ

A
f

·

dpA
dq

, because ˆtA ∥

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
dq + λ

B
∥

·

dpB

dq
- eˆβ (Combined contribution of spine-direction forces at A and B)
4.
λ

A
⊥

·

dpA
dq + λ

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
(Combined contribution of perpendicular forces along the direction orthogonal to the spine)

5.

ˆtB =

1
q
1 + (h

′(xB))²

"
1
h

′
(xB)
, nˆB =

1
q
1 + (h

′(xB))²

"
−h

′
(xB)

1

### 2.4 Zig-Zag Terrain

The zig-zag terrain is defined by a periodic piecewise function y = h(x

I
), with period T = 2r + d

and height h = r tan θ. For each point x

I ∈ R, define xk = x

I mod T. Then:

h(x

I
) =

tan θ · xk, | xk ∈ [0, r]

tan θ · (2r − xk), xk ∈ [r, 2r]

0, | xk ∈ [2r, 2r + d]

Here, in order to make the terrain differentiable at any point, we can use fourier series to approximate the terrain like:

h(x

I

) = 8r tan θ
π

2

X

N

n=1,3,5,...

1
n²

cos
2πnx
2r + d

### 2.5 Dynamics

Generalized coordinate: p

x
A

, l1, l2, l3
terrain function: h(x)

p

x
B

: (p

x
B − p

x
B

)

2 + (h(p

x
B

) − h(p

x
B

))² =

l

4
2
l

2
2+(l

2
3−l

2/1)

2
β : β = arcsin
(p

x
B+cos(β)·l3)−(p

x
A+cos(β)·l1)
l2

rcom =

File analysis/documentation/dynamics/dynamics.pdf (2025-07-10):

## Dynamics

Jerry Wu

July 3, 2025

Generalized coordinate: p

x
A, l1, l2, l3

Terrain function: h(x)

p

x
B solved from: (p

x
B − p

x
A)

2 + (h(p

x
B) − h(p

x

A))² =

l

4
2
l

2
2 + (l

2
3 − l

2/1)

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
B − p

x

A) + -
h(p

x
B) − h(p

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
B − p

x

A) + -
h(p

x
B) − h(p

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
2 l1

l

2
3 − l

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
3 − l

2/122 p
x
B − p

x
A
+
h(p

x
B) − h(p

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
3 − l

2/12
− 1 l

5
2
l

2
2 +
l

2
3 − l

2/122 p
x
B − p

x
A
+
h(p

x
B) − h(p

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
2 l3

l

2
3 − l

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
3 − l

2/122 p
x
B − p

x
A
+
h(p

x
B) − h(p

x
A)
h

′(p

x
B)

β solved from:

ω = β = arcsin
(p

x
B + cos(β)l3) − (p

x
A + cos(β)l1)
l2

β˙ =

p˙

x
B − p˙

x
A + cos β(

˙

l3 − ˙

l1) − ˙
l2 sin β
l2 cos β + sin β(l3 − l1)

ω¨ = β¨ =

ND˙ | − ND˙
| D²

N = ˙p

x
B − p˙

x
A + cos β

˙

l3 − ˙
l1

− ˙
l2 sin β, | (1)

D = l2 cos β + sin β

l3 − l1
, | (2)

N˙ = ¨p
x
B − p¨

x

A − sin β β˙

˙

l3 − ˙
l1
+ cos β

¨l3 − ¨l1

− ¨l2 sin β − ˙

l2 cos β β,˙ | (3)

D˙ = ˙

l2 cos β − l2 sin β β˙ + cos β β˙
l3 − l1
+ sin β

˙

l3 − ˙
l1
. | (4)

rcom =

p

x
A
h(p

x
A)
+ l1
cos(β)
sin(β)
+

1
2

l2

sin(β)
− cos(β)

r˙ com =

p˙

x
A
h

′
(p

x
A) · p˙

x
A
+ ˙
l1
cos β
sin β
+ l1β˙
− sin β
cos β

+

1
2

˙
l2
sin β
− cos β
+

1
2

l2β˙

cos β
sin β

¨rcom =

p¨

x
A
h

′′(p
x
A)( ˙p

x
A)

2 + h

′
(p

x
A) · p¨

x
A

+ ¨l1

cos β
sin β
+ 2˙
l1β˙
− sin β
cos β

+ l1β¨

− sin β
cos β
+ l1(β˙)
2
− cos β
− sin β

+

1
2

¨l2

sin β
− cos β
+ ˙
l2β˙
cos β
sin β

+

1
2

l2β¨

cos β
sin β
+

1
2

l2(β˙)
2
− sin β
cos β

Projection Vector:

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
B + cos(β)l3) − (p

x
A + cos(β)l1)
l2

2
+

sin(β)(l3 − l1)
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
− cos(β)

s
1 −
(p

x
B + cos(β)l3) − (p

x
A + cos(β)l1)
l2

2
+

sin(β)(l3 − l1)
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
B − p

x
A + cos(β)(l3 − l1))
s
1 −
(p

x
B + cos(β)l3) − (p

x
A + cos(β)l1)
l2

2
+

sin(β)(l3 − l1)
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
+ cos(β)

s
1 −
(p

x
B + cos(β)l3) − (p

x
A + cos(β)l1)
l2

2
+

sin(β)(l3 − l1)
l2

∂rcom
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
+ l1

dβ
dpx
A
− sin(β)
cos(β)
+

1
2

l2

dβ
dpx
A
cos(β)
sin(β)

∂rcom
∂l1

=

cos(β)
sin(β)
+ l1

dβ
dl1
− sin(β)
cos(β)
+

1
2

l2

dβ
dl1
cos(β)
sin(β)

∂rcom
∂l2

=

1
2
sin(β)
− cos(β)
+

1
2

l2

dβ
dl2
cos(β)
sin(β)
+ l1

dβ
dl2
− sin(β)
cos(β)

∂rcom
∂l3

= l1 ·

∂β
∂l3
− sin(β)
cos(β)
+

1
2

l2 ·

∂β
∂l3
cos(β)
sin(β)

d’lambere formula:
X

i

(Fg − m¨rcom)δi +

X

i

(τfA + τfB + τA1 + τA2 + τB1 + τB2 − Iω¨)δi = 0

for torque, we have:

rA = −l1

cos(β)
sin(β)
−

1
2

l2

sin(β)
− cos(β)

rB =

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
− l1
cos(β)
sin(β)
−

1
2

l2

sin(β)
− cos(β)

And:
Fg =
0

mg

τfA = (−l1

cos(β)
sin(β)
−

1
2

l2

sin(β)
− cos(β)
) × fA
1
h

′
(x

x
P

)

τA1 = (−l1

cos(β)
sin(β)
−

1
2

l2

sin(β)
− cos(β)
) × λ1
cos(β)
sin(β)
= −

1
2

λ1l2

τA2 = (−l1

cos(β)
sin(β)
−

1
2

l2

sin(β)
− cos(β)
) × λ2
sin(β)
− cos(β)
= λ2l1

τfB = (
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
− l1
cos(β)
sin(β)
−

1
2

l2

sin(β)
− cos(β)
) × fA
1
h

′
(x

x
P

)

τB1 = (
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
− l1
cos(β)
sin(β)
−

1
2

l2

sin(β)
− cos(β)
) × λ1
cos(β)
sin(β)
=

1
2

λ1l2

τB2 = (
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
− l1
cos(β)
sin(β)
−

1
2

l2

sin(β)
− cos(β)
) × λ2
sin(β)
− cos(β)
= λ2l3

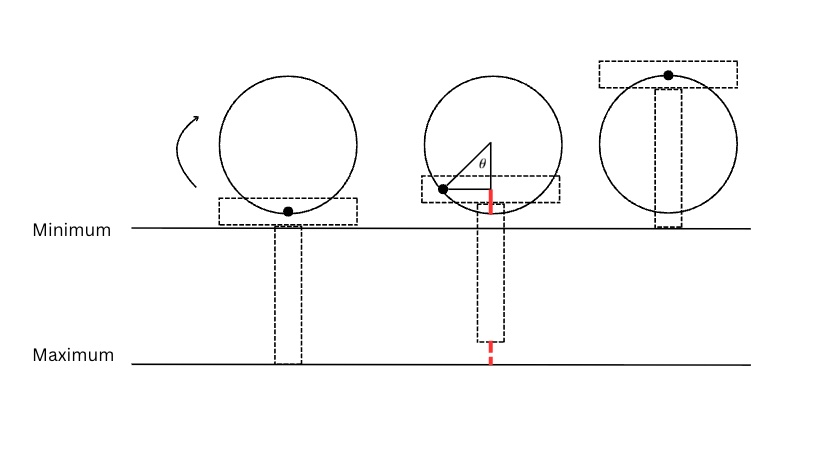
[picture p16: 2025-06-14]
analysis/figs/rotatory_wheel.jpg

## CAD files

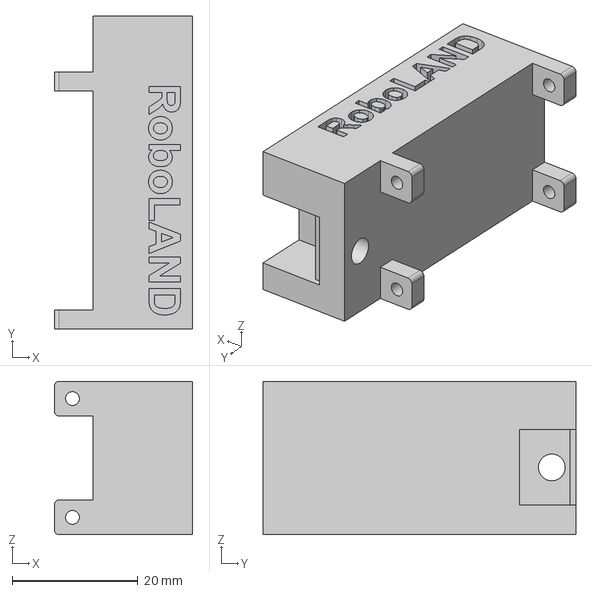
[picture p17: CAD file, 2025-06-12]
CAD/Extension Plate Type 1.step
22.0 x 49.8 x 24.4 mm

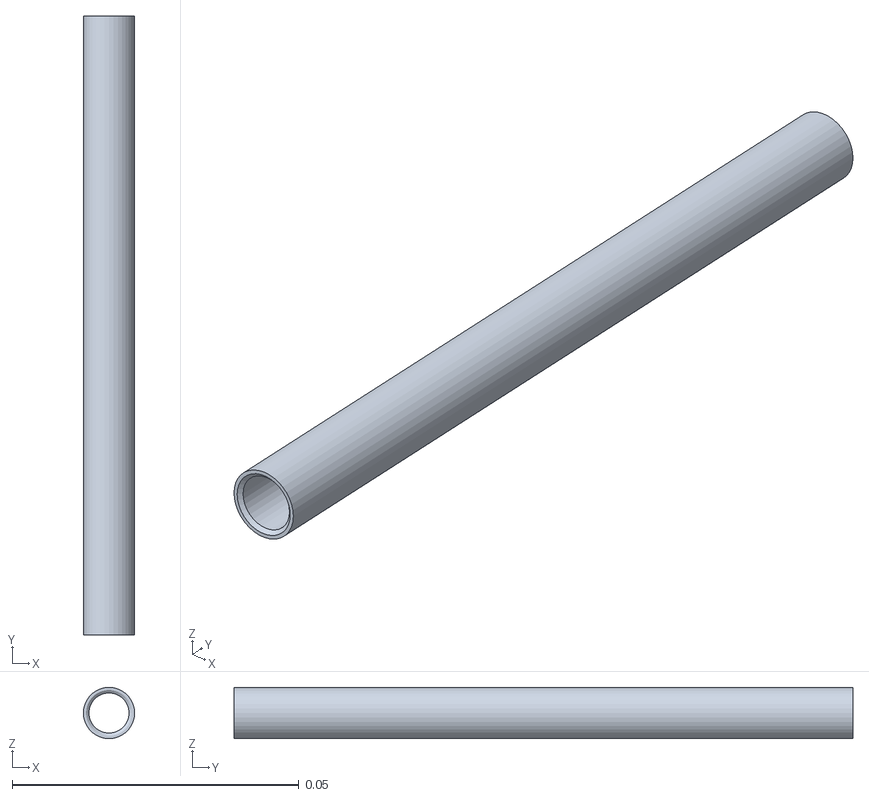
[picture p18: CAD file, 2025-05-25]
simulation/Blender/BECOV2/meshes/stl/SHAFT.stl
0.00895 x 0.108 x 0.00895

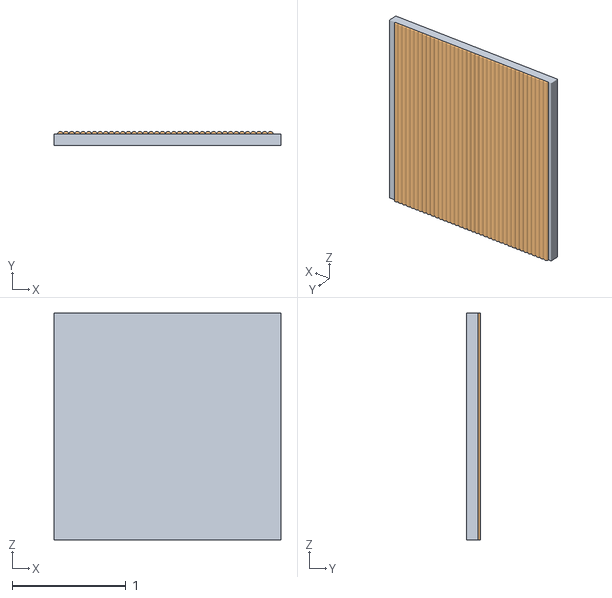
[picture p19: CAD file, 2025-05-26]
simulation/Blender/Terrain/terrain1/terrain1.obj
2.00 x 0.125 x 2.00

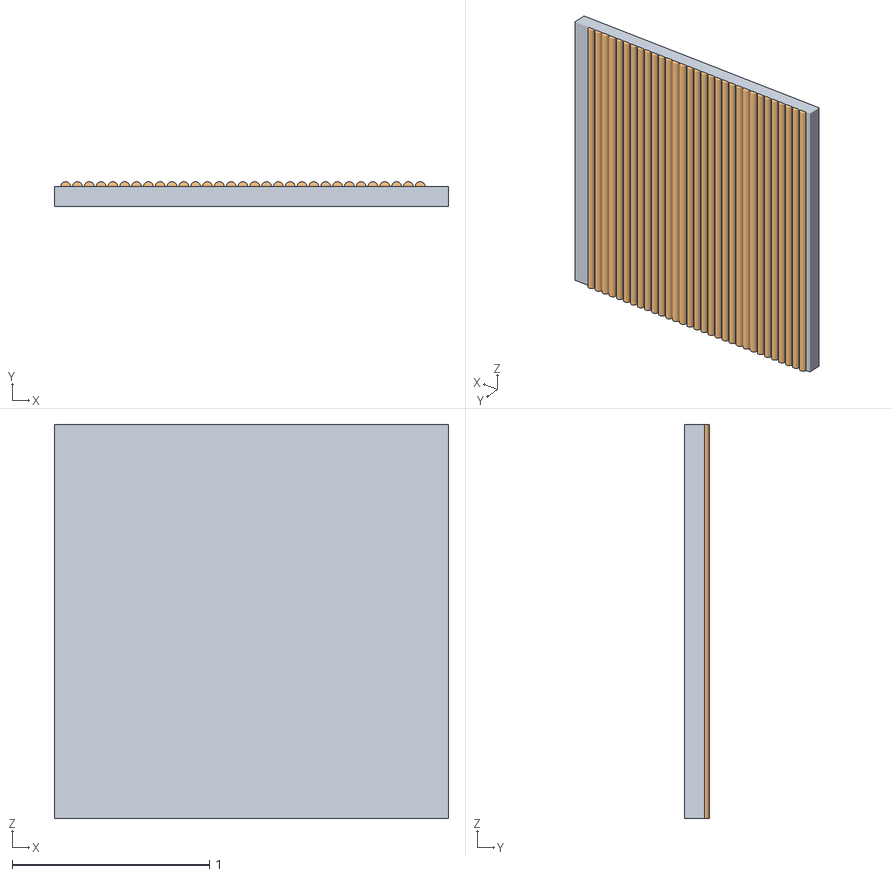
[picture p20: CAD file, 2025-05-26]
simulation/Blender/Terrain/terrain2/terrain2.obj
2.00 x 0.125 x 2.00

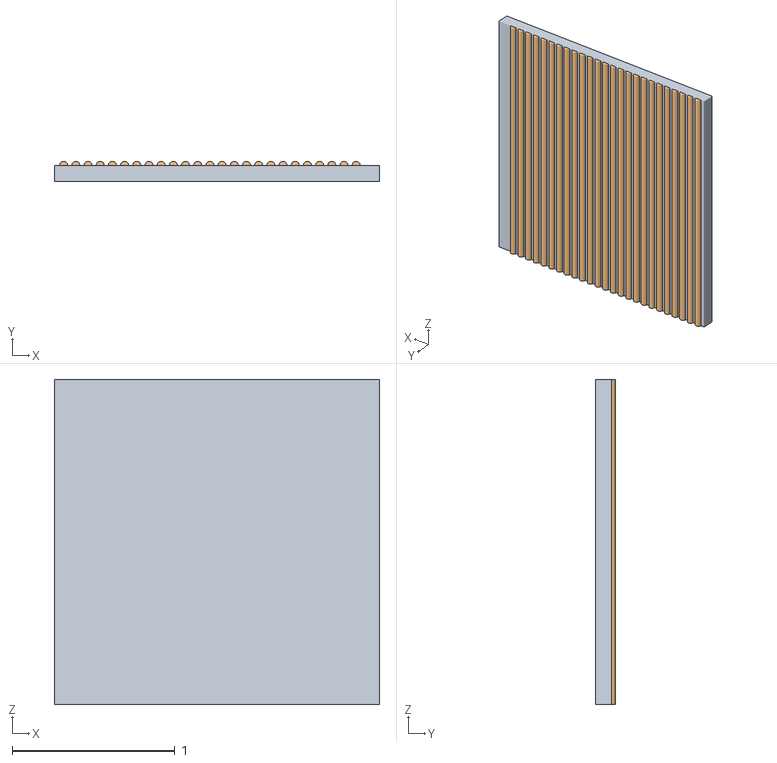
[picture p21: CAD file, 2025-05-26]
simulation/Blender/Terrain/terrain3/terrain3.obj
2.00 x 0.125 x 2.00

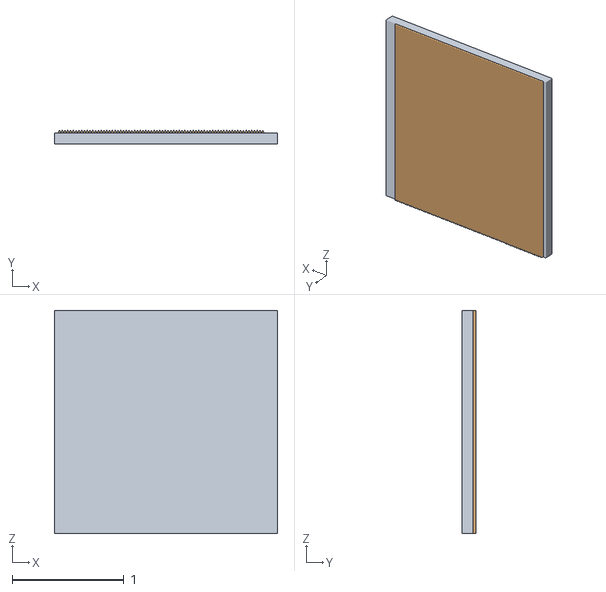
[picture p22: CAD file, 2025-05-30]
simulation/Blender/Terrain/terrain4/terrain4.obj
2.00 x 0.125 x 2.00

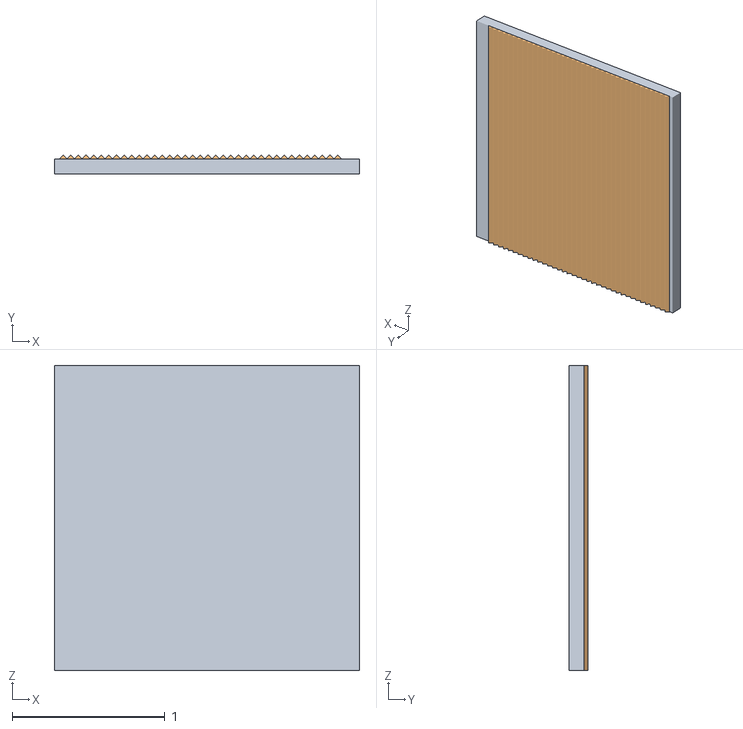
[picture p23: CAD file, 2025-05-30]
simulation/Blender/Terrain/terrain6/terrain6.obj
2.00 x 0.125 x 2.00

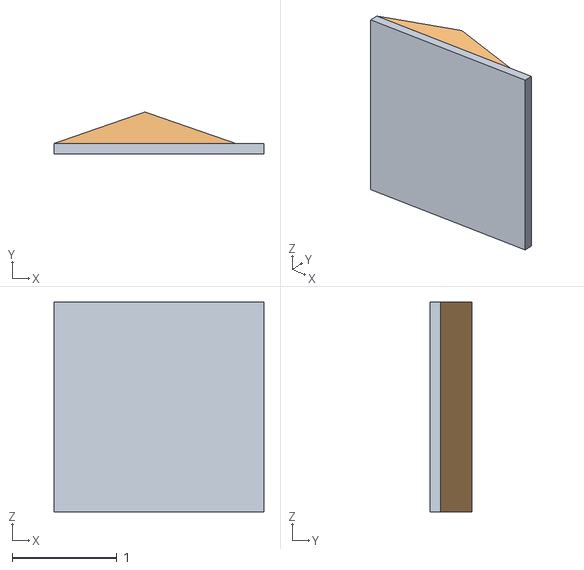
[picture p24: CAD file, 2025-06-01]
simulation/Blender/Terrain/terrain8/terrain8.obj
2.00 x 0.4 x 2.00

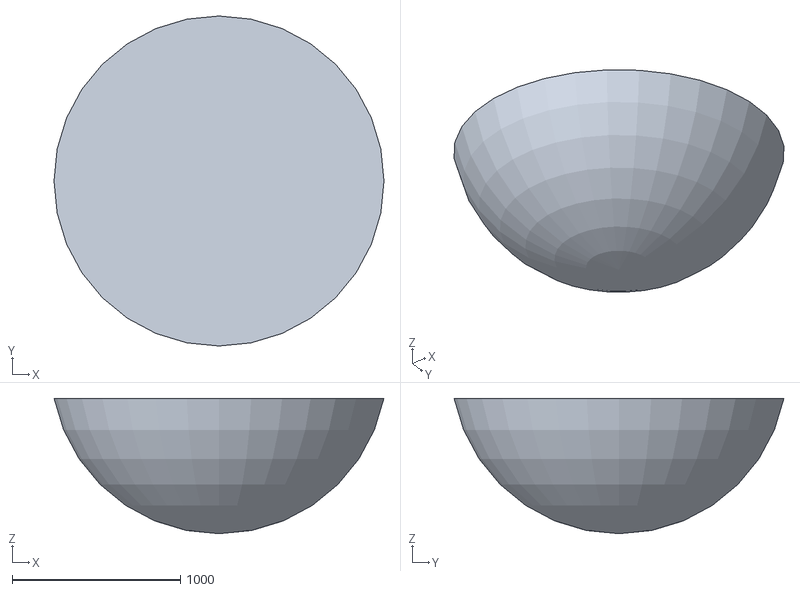
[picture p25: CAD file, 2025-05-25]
simulation/Gazebo/BECOV2_description/meshes/stl/Sphere.004.stl
1961.6 x 1961.6 x 804.9

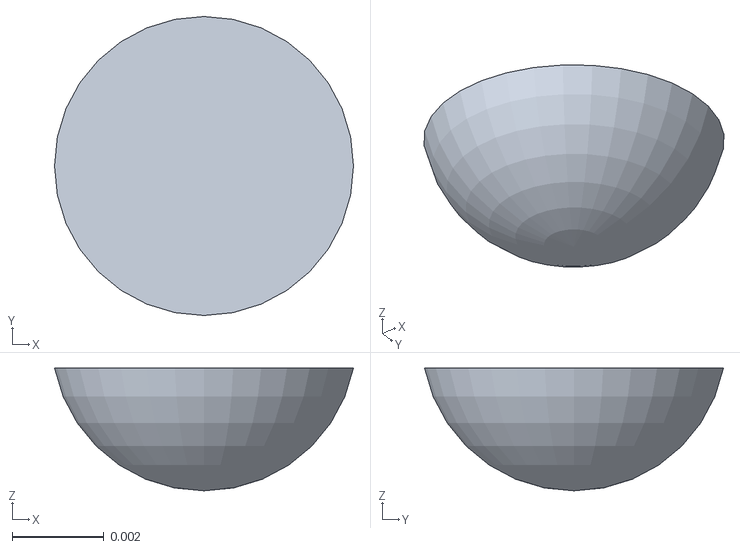
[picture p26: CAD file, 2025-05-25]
simulation/Gazebo/Blender/BECOV2/meshes/stl/Sphere.002.stl
0.00652 x 0.00652 x 0.00267

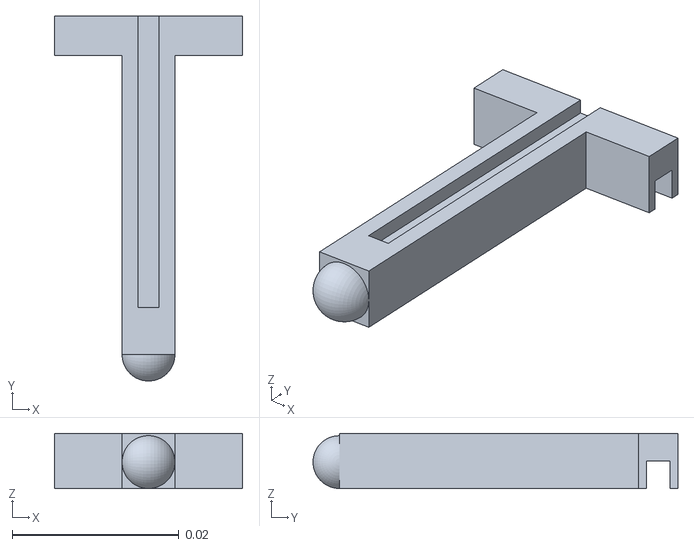
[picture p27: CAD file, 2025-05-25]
simulation/Webots/meshes/LEG_LEFT_RIGHT.stl
0.0226 x 0.0438 x 0.0066

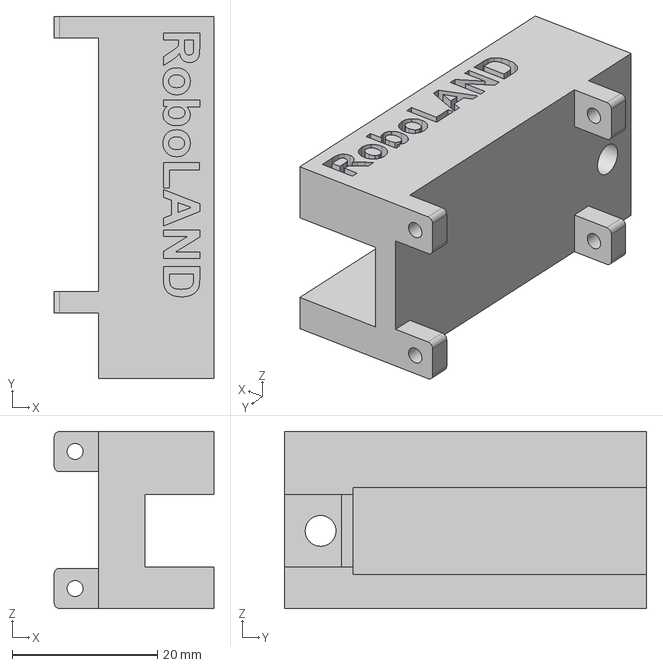
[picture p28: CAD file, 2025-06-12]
CAD/Extension Plate Type 3.step
22.0 x 50.0 x 24.4 mm

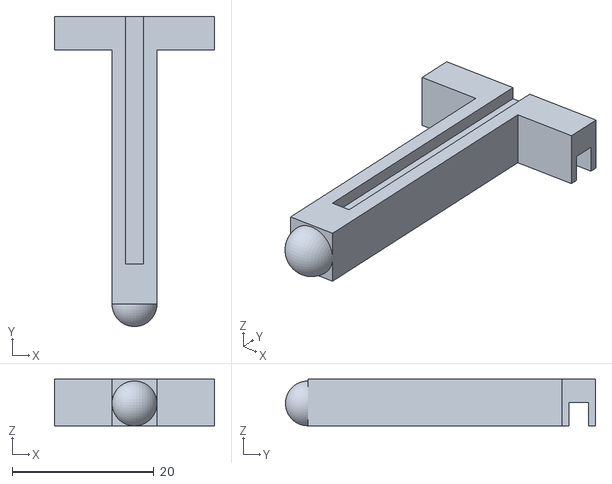
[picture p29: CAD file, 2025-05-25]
simulation/Gazebo/BECOV2_description/meshes/stl/LEG_LEFT_RIGHT.stl
22.6 x 43.8 x 6.60

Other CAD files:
simulation/Blender/Terrain/terrain5/terrain5.obj
simulation/Blender/Terrain/terrain7/terrain7.obj
simulation/Blender/Terrain/terrain9/terrain9.obj
simulation/Blender/BECOV2/meshes/stl/Sphere.001.stl
CAD/Base Plate Type 1.step
CAD/l12_100mm_in.step
CAD/l12_100mm_out.step
simulation/Blender/BECOV2/meshes/stl/LEG_LEFT_LEFT.stl
simulation/Blender/BECOV2/meshes/stl/LEG_RIGHT_RIGHT.001.stl
simulation/Blender/BECOV2/meshes/stl/LEG_RIGHT_RIGHT.stl
simulation/Blender/Terrain/assets/materials/plastic-white-14_8b22398a-027b-4e7b-9760-f3ff1d070261/plastic-white-14_1K_c185bc3d-189e-4e9b-9e8e-6595211ab13f.blend
simulation/Blender/Terrain/terrain1/terrain1.blend
simulation/Blender/Terrain/terrain4/terrain4.blend
simulation/Blender/Terrain/terrain5/terrain5.blend
simulation/Blender/Terrain/terrain7/terrain7 2.blend
simulation/Blender/Terrain/terrain7/terrain7.blend
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

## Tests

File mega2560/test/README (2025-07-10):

This directory is intended for PlatformIO Test Runner and project tests.

Unit Testing is a software testing method by which individual units of
source code, sets of one or more MCU program modules together with associated
control data, usage procedures, and operating procedures, are tested to
determine whether they are fit for use. Unit testing finds problems early
in the development cycle.

More information about PlatformIO Unit Testing:
- https://docs.platformio.org/en/latest/advanced/unit-testing/index.html
s

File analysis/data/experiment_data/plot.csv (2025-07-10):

Leg0 | Leg1 | Spine | Beta_Acc | Beta
1608.00 | 192.00 | 111.13 | 0.43 | -1.10
1608.00 | 192.00 | 111.13 | -0.12 | -1.10
1596.00 | 204.00 | 111.64 | -0.91 | -1.13
1584.00 | 216.00 | 112.18 | 0.18 | -1.12
1584.00 | 216.00 | 112.18 | -0.37 | -1.13
1572.00 | 228.00 | 112.76 | 1.77 | -1.08
1572.00 | 228.00 | 112.76 | -0.18 | -1.09
1560.00 | 240.00 | 113.36 | -0.06 | -1.09
1560.00 | 240.00 | 113.36 | 0.61 | -1.07
1548.00 | 252.00 | 113.99 | -0.67 | -1.09
1548.00 | 252.00 | 113.99 | 0.43 | -1.08
1536.00 | 264.00 | 114.65 | 0.43 | -1.07
1524.00 | 276.00 | 115.34 | 1.46 | -1.03
1524.00 | 276.00 | 115.34 | 1.16 | -1.00
1512.00 | 288.00 | 116.06 | -0.12 | -1.00
1512.00 | 288.00 | 116.06 | -0.49 | -1.01
1500.00 | 300.00 | 116.80 | 0.67 | -0.99
1500.00 | 300.00 | 116.80 | 0.12 | -0.99
1488.00 | 312.00 | 117.57 | -0.06 | -0.99
1488.00 | 312.00 | 117.57 | -0.06 | -0.99
1476.00 | 324.00 | 118.37 | 0.73 | -0.97
1476.00 | 324.00 | 118.37 | 0.73 | -0.95
1464.00 | 336.00 | 119.20 | 1.40 | -0.91
1452.00 | 348.00 | 120.05 | 1.28 | -0.88
1452.00 | 348.00 | 120.05 | -0.06 | -0.88
1440.00 | 360.00 | 120.93 | -0.18 | -0.89
1440.00 | 360.00 | 120.93 | 0.06 | -0.88
1428.00 | 372.00 | 121.83 | 0.61 | -0.87
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

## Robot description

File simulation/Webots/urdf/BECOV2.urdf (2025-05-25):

<robot name="BECOV2" version="1.0">
  <joint name="LEG_LEFT_LEFT_JOINT" type="prismatic">
    <limit lower="-0.0300" upper="0.00000" effort="1.00000" velocity="0.10000"/>
    <origin rpy="0.00000 0.00000 0.00000" xyz="-0.02465 -0.03079 -0.04494"/>
    <parent link="VISUAL_LEFTBODY_LINK"/>
    <child link="VISUAL_LEG_LEFT_LEFT_LINK"/>
    <axis xyz="0.00000 0.00000 1.00000"/>
  </joint>
  <joint name="LEG_LEFT_RIGHT_JOINT" type="prismatic">
    <limit lower="-0.0300" upper="0.00000" effort="1.00000" velocity="0.10000"/>
    <origin rpy="0.00000 0.00000 0.00000" xyz="0.02372 -0.03079 -0.04494"/>
    <parent link="VISUAL_LEFTBODY_LINK"/>
    <child link="VISUAL_LEG_LEFT_RIGHT_LINK"/>
    <axis xyz="0.00000 0.00000 1.00000"/>
  </joint>
  <joint name="LEG_RIGHT_LEFT_JOINT" type="prismatic">
    <limit lower="-0.0300" upper="0.00000" effort="1.00000" velocity="0.10000"/>
    <origin rpy="0.00000 0.00000 0.00000" xyz="0.02646 0.01264 -0.04295"/>
    <parent link="VISUAL_RIGHTBODY_LINK"/>
    <child link="VISUAL_LEG_RIGHT_LEFT_LINK"/>
    <axis xyz="0.00000 0.00000 1.00000"/>
  </joint>
  <joint name="LEG_RIGHT_RIGHT_JOINT" type="prismatic">
    <limit lower="-0.0300" upper="0.00000" effort="1.00000" velocity="0.10000"/>
    <origin rpy="0.00000 0.00000 0.00000" xyz="-0.02190 0.01264 -0.04295"/>
    <parent link="VISUAL_RIGHTBODY_LINK"/>
    <child link="VISUAL_LEG_RIGHT_RIGHT_LINK"/>
    <axis xyz="0.00000 0.00000 1.00000"/>
  </joint>
  <joint name="RIGHTBODY_JOINT" type="fixed">
    <origin rpy="0.00000 0.00000 0.00000" xyz="-0.00067 0.03262 -0.02065"/>
    <parent link="VISUAL_SHAFT_LINK"/>
    <child link="VISUAL_RIGHTBODY_LINK"/>
  </joint>
  <joint name="SHAFT_JOINT" type="prismatic">
    <limit lower="0.00000" upper="0.09000" effort="1.00000" velocity="0.10000"/>
    <origin rpy="0.00000 0.00000 0.00000" xyz="-0.00207 0.06764 0.01866"/>
    <parent link="VISUAL_LEFTBODY_LINK"/>
    <child link="VISUAL_SHAFT_LINK"/>
    <axis xyz="0.00000 1.00000 0.00000"/>
  </joint>
  <link name="VISUAL_LEFTBODY_LINK">
    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
    <inertial>
      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
      <origin rpy="0.00000 0.00000 0.00000" xyz="-0.00036 -0.01043 -0.00849"/>
      <mass value="0.00100"/>
    </inertial>
    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
  </link>
  <link name="VISUAL_LEG_LEFT_LEFT_LINK">
    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
    <inertial>
      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
      <origin rpy="0.00000 0.00000 0.00000" xyz="0.00019 -0.00045 -0.01199"/>
      <mass value="0.00100"/>
    </inertial>
    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
  </link>
  <link name="VISUAL_LEG_LEFT_RIGHT_LINK">
    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
    <inertial>
      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
      <origin rpy="0.00000 0.00000 0.00000" xyz="-0.00030 -0.00045 -0.01199"/>
      <mass value="0.00100"/>
    </inertial>
    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
  </link>
  <link name="VISUAL_LEG_RIGHT_LEFT_LINK">
    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
    <inertial>
      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
      <origin rpy="0.00000 0.00000 0.00000" xyz="-0.00030 0.00035 -0.01199"/>
      <mass value="0.00100"/>
    </inertial>
    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
  </link>
  <link name="VISUAL_LEG_RIGHT_RIGHT_LINK">
    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
    <inertial>
      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
      <origin rpy="0.00000 0.00000 0.00000" xyz="0.00019 0.00035 -0.01199"/>
      <mass value="0.00100"/>
    </inertial>
    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
  </link>
  <link name="VISUAL_RIGHTBODY_LINK">
    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
    <inertial>
      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
      <origin rpy="0.00000 0.00000 0.00000" xyz="0.00185 -0.01699 0.01912"/>
      <mass value="0.00100"/>
    </inertial>
    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
  </link>
  <link name="VISUAL_SHAFT_LINK">
    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
    <inertial>
      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
      <origin rpy="0.00000 0.00000 0.00000" xyz="-0.00003 -0.00366 -0.00153"/>
      <mass value="0.00100"/>
    </inertial>
    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
  </link>
</robot>

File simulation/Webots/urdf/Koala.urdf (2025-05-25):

<?xml version="1.0"?>
<robot name="/Users/jerrywu/Library/Mobile Documents/com~apple~CloudDocs/Desktop/Roboland/Multi-Agent/BECOv2/simulation/BECOV2_ws/urdf/Koala.urdf" xmlns:xacro="http://ros.org/wiki/xacro">
  <link name="base_link">
    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
  </link>
  <link name="ds15">
  </link>
  <joint name="base_link_ds15_joint" type="fixed">
    <parent link="base_link"/>
    <child link="ds15"/>
    <origin xyz="0.175 0.015 0.102" rpy="1.570807 -0.000005 0.100001"/>
  </joint>
  <link name="ds14">
  </link>
  <joint name="base_link_ds14_joint" type="fixed">
    <parent link="base_link"/>
    <child link="ds14"/>
    <origin xyz="0.169 0.04 0.102" rpy="1.570806 -0.000005 0.2"/>
  </joint>
  <link name="ds13">
  </link>
  <joint name="base_link_ds13_joint" type="fixed">
    <parent link="base_link"/>
    <child link="ds13"/>
    <origin xyz="0.16 0.07 0.102" rpy="1.570806 -0.000007 0.300001"/>
  </joint>
  <link name="ds12">
  </link>
  <joint name="base_link_ds12_joint" type="fixed">
    <parent link="base_link"/>
    <child link="ds12"/>
    <origin xyz="0.14 0.125 0.102" rpy="1.570801 -0.00001 0.8"/>
  </joint>
  <link name="ds11">
  </link>
  <joint name="base_link_ds11_joint" type="fixed">
    <parent link="base_link"/>
    <child link="ds11"/>
    <origin xyz="0.055 0.14 0.102" rpy="1.570793 -0.000011 1.57079"/>
  </joint>
  <link name="ds10">
  </link>
  <joint name="base_link_ds10_joint" type="fixed">
    <parent link="base_link"/>
    <child link="ds10"/>
    <origin xyz="-0.05 0.14 0.102" rpy="1.570793 -0.00001 1.57099"/>
  </joint>
  <link name="ds9">
  </link>
  <joint name="base_link_ds9_joint" type="fixed">
    <parent link="base_link"/>
    <child link="ds9"/>
    <origin xyz="-0.12 0.125 0.102" rpy="1.570787 -0.000005 2.352385"/>
  </joint>
  <link name="ds8">
  </link>
  <joint name="base_link_ds8_joint" type="fixed">
    <parent link="base_link"/>
    <child link="ds8"/>
    <origin xyz="-0.13 0.0475 0.107" rpy="1.570786 0.000005 3.141587"/>
  </joint>
  <link name="ds7">
  </link>
  <joint name="base_link_ds7_joint" type="fixed">
    <parent link="base_link"/>
    <child link="ds7"/>
    <origin xyz="-0.13 -0.0475 0.107" rpy="1.570786 0.000005 3.141587"/>
  </joint>
  <link name="ds6">
  </link>
  <joint name="base_link_ds6_joint" type="fixed">
    <parent link="base_link"/>
    <child link="ds6"/>
    <origin xyz="-0.12 -0.125 0.102" rpy="1.57079 0.00001 -2.4232"/>
  </joint>
  <link name="ds5">
  </link>
  <joint name="base_link_ds5_joint" type="fixed">
    <parent link="base_link"/>
    <child link="ds5"/>
    <origin xyz="-0.05 -0.14 0.102" rpy="1.5708 0.00001 -1.5708"/>
  </joint>
  <link name="ds4">
  </link>
  <joint name="base_link_ds4_joint" type="fixed">
    <parent link="base_link"/>
    <child link="ds4"/>
    <origin xyz="0.055 -0.14 0.102" rpy="1.5708 0.00001 -1.5708"/>
  </joint>
  <link name="ds3">
  </link>
  <joint name="base_link_ds3_joint" type="fixed">
    <parent link="base_link"/>
    <child link="ds3"/>
    <origin xyz="0.14 -0.12 0.102" rpy="1.570806 0.000005 -0.800003"/>
  </joint>
  <link name="ds2">
  </link>
  <joint name="base_link_ds2_joint" type="fixed">
    <parent link="base_link"/>
    <child link="ds2"/>
    <origin xyz="0.16 -0.07 0.102" rpy="1.570808 0 -0.3"/>
  </joint>
  <link name="ds1">
  </link>
  <joint name="base_link_ds1_joint" type="fixed">
    <parent link="base_link"/>
    <child link="ds1"/>
    <origin xyz="0.169 -0.04 0.102" rpy="1.570807 -0.000001 -0.2"/>
  </joint>
  <link name="ds0">
  </link>
  <joint name="base_link_ds0_joint" type="fixed">
    <parent link="base_link"/>
    <child link="ds0"/>
    <origin xyz="0.175 -0.015 0.102" rpy="1.570807 -0.000002 -0.1"/>
  </joint>
  <link name="wheel(6)">
    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
  </link>
  <joint name="base_link_wheel(6)_joint" type="fixed">
    <parent link="base_link"/>
    <child link="wheel(6)"/>
    <origin xyz="-0.09 -0.1425 0.0425" rpy="1.5708 0.00001 -1.5708"/>
  </joint>
  <joint name="right wheel motor" type="continuous">
    <parent link="base_link"/>
    <child link="wheel(5)"/>
    <axis xyz="-1 0.000007 -0.000007"/>
    <limit effort="10" velocity="10"/>
    <origin xyz="0 0 0.0425" rpy="-1.100522 0.00001 -1.5708"/>
  </joint>
  <link name="wheel(5)">
    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
  </link>
  <link name="wheel(4)">
    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
  </link>
  <joint name="base_link_wheel(4)_joint" type="fixed">
    <parent link="base_link"/>
    <child link="wheel(4)"/>
    <origin xyz="0.2325 -0.142501 0.042501" rpy="1.5708 0.00001 -1.5708"/>
  </joint>
  <link name="wheel(3)">
    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
  </link>
  <joint name="base_link_wheel(3)_joint" type="fixed">
    <parent link="base_link"/>
    <child link="wheel(3)"/>
    <origin xyz="-0.09 0.1425 0.0425" rpy="1.5708 0.00001 -1.5708"/>
  </joint>
  <joint name="left wheel motor" type="continuous">
    <parent link="base_link"/>
    <child link="wheel(2)"/>
    <axis xyz="-1 -0.000002 -0.00001"/>
    <limit effort="10" velocity="10"/>
    <origin xyz="0 0 0.0425" rpy="-0.184141 0.00001 -1.5708"/>
  </joint>
  <link name="wheel(2)">
    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
  </link>
  <link name="wheel(1)">
    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
  </link>
  <joint name="base_link_wheel(1)_joint" type="fixed">
    <parent link="base_link"/>
    <child link="wheel(1)"/>
    <origin xyz="-0.0525 0.1425 0.042499" rpy="1.5708 0.00001 -1.5708"/>
  </joint>
</robot>

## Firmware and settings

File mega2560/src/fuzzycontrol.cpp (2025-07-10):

#include <Arduino.h>
#include <DFRobot_BMI160.h>
#include "actuator.h"
#include "motor.h"

Actuator spine(4, A0);         // PWM pin: 4, Feedback pin: A0
Motor leg0(Serial1, 0);        // Motor ID 0
Motor leg1(Serial1, 1);        // Motor ID 1

DFRobot_BMI160 bmi160;
const uint8_t I2C_ADDR = 0x69;  // IMU Address

const float spineMin = 107.1f;
const float spineMax = 251.9f;
const int legAngleMin = 0;
const int legAngleMax = 1800;

const int Period = 15; 
//notes: the minimum period for full extension is 30s
//futhur than that, the linear actuator wouldn't be able to catch
const float omega = 2*PI/Period;
const float offset =  0 ;
const int N_Sample = 300;
float t_k[N_Sample];
float leg0AngleTrajectory[N_Sample];
float leg1AngleTrajectory[N_Sample];
float spinePWMTrajectory[N_Sample];

// IMU setup
const float ACC_LSB_PER_G     = 16384.0;  // For ±2g
const float GYRO_LSB_PER_DPS  = 16.4;     // For ±2000 °/s
int16_t imu_data[6] = {0};  // Gx, Gy, Gz, Ax, Ay, Az
float beta_acc = 0.0f;;
float beta = 0.0f;  
unsigned long lastMicros = 0;

unsigned long startTime = 0;
bool isRunning = false;
// refreshing frequency control (5ms, 200Hz)
const int updateIntervalMs = 5;
unsigned long lastUpdateTime = 0;

/// @brief  The detailed formula can be found in analysis sinusoidal_wave_control.ipynb
void sinusoidal_trajectory_generator() {
  for (int i = 0; i < N_Sample; i++) {
    float t = (float)i / N_Sample * Period;
    t_k[i] = t;

    float pwm = ((spineMax - spineMin) / 2.0) * cos(omega * t + offset)
                + ((spineMax + spineMin) / 2.0);

    spinePWMTrajectory[i] = pwm;

    float theta0 = acos(cos(omega * t ));
    float theta1 = acos(cos(omega * t + PI));
    float leg0 = theta0 / PI * (legAngleMax-legAngleMin);
    float leg1 = theta1 / PI * (legAngleMax-legAngleMin);
    leg0AngleTrajectory[i] = leg0;
    leg1AngleTrajectory[i] = leg1;
  }
}

void setup() {
  Serial.begin(115200);
  Serial1.begin(115200);

  Serial.println("Mega2560 Triangle Wave Controller Ready.");

  Serial.println("Generating Sinusoidal Trajectory for Legs and Spine...");
  sinusoidal_trajectory_generator();
  Serial.println("Sinusoidal Trajectory Generated");

  Serial.println("Initializing Spine and Leg to starting position");
  spine.setPosition(spinePWMTrajectory[0]);
  leg0.sendAngle(leg0AngleTrajectory[0]);
  leg1.sendAngle(leg1AngleTrajectory[0]);
  delay(5000);

  if (bmi160.softReset() != BMI160_OK) {
    Serial.println("Reset failed"); while (1);
  }
  if (bmi160.I2cInit(I2C_ADDR) != BMI160_OK) {
    Serial.println("Init failed"); while (1);
  }
  lastMicros = micros();
  Serial.println("BMI160 ready (DFRobot driver)");

  Serial.println("Initialized. Press 's' to start.");
}

void loop() {
  if (Serial.available()) {
    char c = Serial.read();
    if (c == 's' || c == 'S') {
      isRunning = !isRunning;
      if (isRunning) {
        Serial.println("Oscillator started.");
        startTime = millis();  // record start time for each loop
        lastUpdateTime = millis();
      } else {
        Serial.println("Oscillator stopped.");
      }
    }
  }

  if (!isRunning) return;

  unsigned long currentMillis = millis();

  // refreshing frequency control
  if(currentMillis - lastUpdateTime < updateIntervalMs) return;
  lastUpdateTime = currentMillis;

  float elapsed = (currentMillis - startTime) / 1000.0;  // convert to second
  float t_now = fmod(elapsed, Period);  // find t in period [0, Period]
  int index = (int)(t_now / Period * N_Sample);
  index = constrain(index, 0, N_Sample - 1);  // find closest t_k

  spine.setPosition(spinePWMTrajectory[index]);
  leg0.sendAngle(leg0AngleTrajectory[index]);
  leg1.sendAngle(leg1AngleTrajectory[index]);

  if (bmi160.getAccelGyroData(imu_data) == BMI160_OK){
    beta_acc = imu_data[0] / GYRO_LSB_PER_DPS;

    unsigned long nowMicros = micros();
    float dt = (nowMicros - lastMicros) * 1e-6f;
    lastMicros = nowMicros;

    beta += beta_acc * dt;
  }

  // Serial.print(">");
  // Serial.print("Leg0:");
  Serial.print(leg0AngleTrajectory[index]);
  Serial.print(",");

  // Serial.print("Leg1:");
  Serial.print(leg1AngleTrajectory[index]);
  Serial.print(",");

  // Serial.print("Spine:");
  Serial.print(spinePWMTrajectory[index]);
  Serial.print(",");
  
  // Serial.print("Beta Acc [°/s]: ");
  Serial.print(beta_acc, 2);
  Serial.print(",");

  // Serial.print("Beta [°]: ");
  Serial.print(beta, 2);
  Serial.println();
}

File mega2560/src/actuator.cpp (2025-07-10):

#include "actuator.h"

Actuator::Actuator(int pwmPin, int feedbackPin, float kp, float kd,
                   int pwmMax)
    : pwmPin(pwmPin), feedbackPin(feedbackPin),
      kp(kp), kd(kd), pwmMax(pwmMax)
{
    pinMode(feedbackPin, INPUT);
    pinMode(pwmPin, OUTPUT);
}

void Actuator::setPosition(float pos) {
    pos = constrain(pos, 0, pwmMax);  
    analogWrite(pwmPin, pos);
}

void Actuator::setPosition(float pos, bool closedLoop) {
    pos = constrain(pos, 0, pwmMax);

    if (!closedLoop) {
        int pwmVal = map(pos, 0, pwmMax, 0, 255);  
        analogWrite(pwmPin, pwmVal);
        return;
    }

    const float tolerance = 5.0f;
    const unsigned long timeout = 5000;
    unsigned long startTime = millis();

    while (millis() - startTime < timeout) {
        float currentPos = getPosition();
        float error = pos - currentPos;

        if (abs(error) <= tolerance) {
            analogWrite(pwmPin, 0); 
            break;
        }

        int pwmVal = constrain(kp * error, 0, 255);
        analogWrite(pwmPin, pwmVal);
        delay(5);
    }
}


float Actuator::getVoltage() {
    int raw = analogRead(feedbackPin);
    return raw * (vRef / adcMax);
}

float Actuator::getPosition() {
    float v = getVoltage();
    v = constrain(v, vMin, vMax);
    return (1-(v - vMin) / (vMax - vMin)) * pwmMax; // position needs to be reversed
}

void Actuator::setvMin() {
    vMin = getVoltage();
}

void Actuator::setvMax() {
    vMax = getVoltage();
}

float Actuator::getvMin() {
    return vMin;
}

float Actuator::getvMax() {
    return vMax;
}

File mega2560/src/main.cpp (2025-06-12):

#include <Arduino.h>

const int actuatorPin = 4;  // PWM for shaft actuator
int shaft_pwm = 0;

void sendLSSCommand(const char* cmd) {
    Serial1.print(cmd);
    Serial1.print("\r");  // LSS commands require carriage return
    Serial.print("[LSS] Sent: ");
    Serial.println(cmd);
  }

void setup() {
  Serial.begin(115200);       // USB serial monitor
  Serial1.begin(115200);      // UART1 → LSS
  pinMode(actuatorPin, OUTPUT);
  delay(1000);

  Serial.println("Mega2560 LSS phase controller ready.");
  Serial.println("Initializing motors to 45 degrees...");
  Serial.println("Type 0~4 to trigger phase:");
}


void execute_phase(int phase) {
  switch (phase) {
    case 0:
      Serial.println("Phase 0: Reset both motors to 90°");
      sendLSSCommand("#0D0900");
      sendLSSCommand("#1D0900");
      break;
    case 1:
      Serial.println("Phase 1: Motor0 -> 0°, Motor1 -> 180°");
      sendLSSCommand("#0D0000");
      sendLSSCommand("#1D01800");
      break;
    case 2:
      Serial.println("Phase 2: Extend shaft");
      shaft_pwm = 255;
      break;
    case 3:
      Serial.println("Phase 3: Motor0 -> 180°, Motor1 -> 0°");
      sendLSSCommand("#0D01800");
      sendLSSCommand("#1D0000");
      break;
    case 4:
      Serial.println("Phase 4: Retract shaft");
      shaft_pwm = 0;
      break;
    default:
      Serial.println("Invalid phase");
      return;
  }

  analogWrite(actuatorPin, shaft_pwm);
  Serial.print("PWM set to: ");
  Serial.println(shaft_pwm);
}

void loop() {
  if (Serial.available()) {
    char c = Serial.read();
    if (c >= '0' && c <= '4') {
      int phase = c - '0';
      execute_phase(phase);
    }
  }
}

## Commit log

2025-04-04 Replace existing repo with new local folder
    [main.cpp]
2025-05-19 simulation create
    [BECOV2.urdf.xacro]
2025-05-26 Webots update
    [plastic-white-14_1K_c185bc3d-189e-4e9b-9e8e-6595211ab13f.blend, terrain1.blend, terrain1.obj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]
2025-06-05 Track CSV files in simulation/Analysis/ with Git LFS
2025-06-05 Re-track CSV files using Git LFS and restore .gitattributes
2025-06-05 file organize
    [df_valid_with_com.csv, df_valid_with_forces.csv, trajectory_log_com1.csv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]
2025-06-12 Restore CAD, analysis, README; rename real to mega2560
    [Base Plate Type 1.step, Extension Plate Type 1.step, Extension Plate Type 3.step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]
2025-06-13 velocity measurement
2025-06-14 Add grid search data
    [df_valid_with_com.csv, df_valid_with_forces.csv, grid_search_with_angles.csv]
